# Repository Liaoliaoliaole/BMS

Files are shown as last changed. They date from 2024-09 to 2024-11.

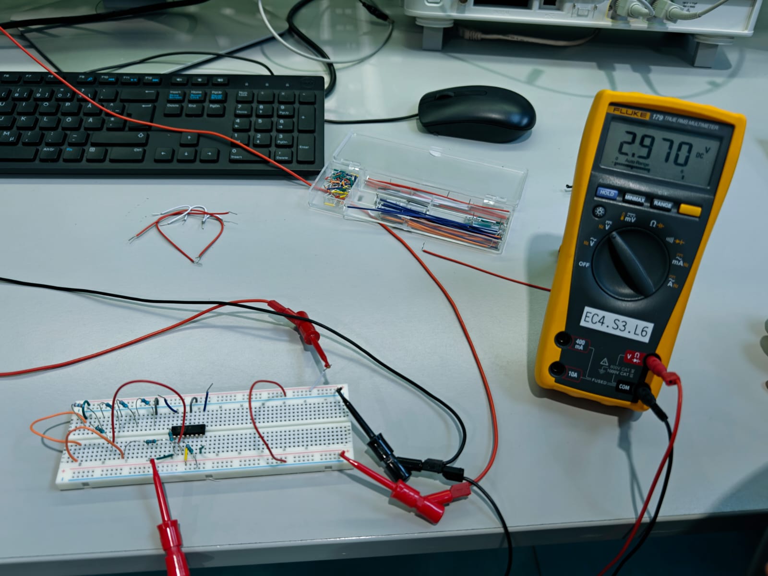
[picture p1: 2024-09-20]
prototyping/Lab1_voltage_measurement/1_LM324N.jpeg

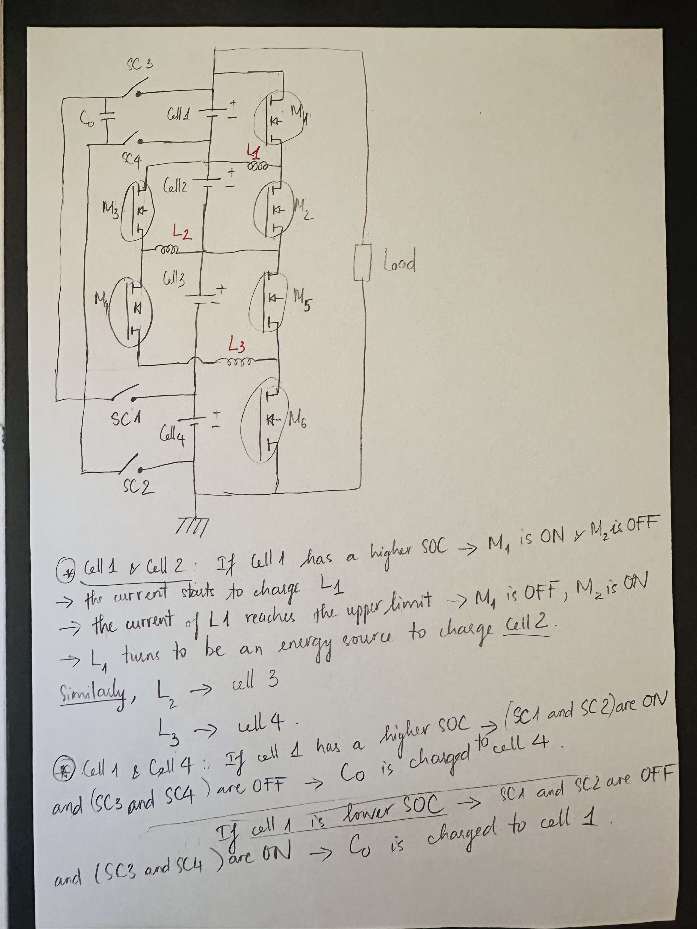
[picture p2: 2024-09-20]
blockdiagram/active_balancing.jpg

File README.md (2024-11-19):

# BMS

# Project Structure

This repository contains the following directories to organize various aspects of the Battery Management System (BMS) project:
Meeting note and scrum report for scrum could be found from [Jira](https://liyuanliull.atlassian.net/jira/software/projects/SCRUM/boards/1/reports).

# `firmware`
The firmware directory includes the BMSServerApp source code. This application runs on the STM32L152RE Nucleo development board.   

## Cross-compilation
### Preconditions:
On Windows:   
- CMake
- Ninja
- STSW-LINK007
- GCC ARM None EABI Compiler

Details of the environment setup can be found in Confluence: [How-To-CrossCompile-BMSServerApp](https://liyuanliull.atlassian.net/wiki/spaces/BMSDEVELOP/pages/426109/How-to+Set+Up+Environment+and+Building+the+BMSServerApp)

### Build scripts
Navigate to the directory where the build script exists.   
Execute the following command in the terminal (such as Windows PowerShell):  
`./build_BMSServerApp.ps1 [-TestBuild]`   

- **Test Build**: Add the optional `-TestBuild` flag to include the testing features in your build, which will enable mock components or extra diagnostics during testing. For example:  
  `./build_BMSServerApp.ps1 -TestBuild`

Then connect the STM32L152RE to your PC, and run:    
`st-flash write BMSServerApp\build\BMSServerApp.bin 0x08000000`   

To remove the build, remove the `build` directory.

## GitHub Actions for CI/CD
The BMSServerApp project also supports automated builds via GitHub Actions. This allows you to build the project in the cloud whenever changes are pushed to the specified branch or a pull request is made.

### Build Types in GitHub Actions:
- The workflow is configured to build three different types: **Debug**, **Release**, and **Test**.
- The **Test** build defines a special `TEST` macro during compilation, enabling mock data and diagnostic features.

### How to Use GitHub Actions:
- **Trigger a Build**: Any push or pull request to the specified branch will automatically trigger the build process.
- **Check Build Status**: Monitor the status of the build in the "Actions" tab of the GitHub repository.
- **Find the Output**:   
  1. Click on the "Actions" tab.
  2. Select the Workflow Run: Find the specific workflow run to view its details.
  3. Scroll down to the "Artifacts" section on the workflow run page. This section shows the files that were uploaded during the workflow execution.
  4. Download the Binary File:  Click on the link for the binary file you want to download (e.g., `BMSServerApp-Debug-bin`, `BMSServerApp-Release-bin`, or `BMSServerApp-Test-bin`).   

# `prototyping`
This directory contains code, configurations, and other resources related to early-stage prototyping of the BMS project. It is used for experimenting with features, creating proof-of-concept implementations, and testing ideas before moving to production.  

- **Breadboard Prototyping**: The breadboard setup for the [current measurement module](https://liyuanliull.atlassian.net/wiki/spaces/BMSDEVELOP/pages/6520833/Voltage+Temperature+and+Current+measurement+Overview) and [temperature measurement prototypes](https://liyuanliull.atlassian.net/wiki/spaces/BMSDEVELOP/pages/8257538/Temperature+Measurement+Module+Prototyping+Documentation.) are stored in confluence.   
- **Calibration Functions**: Software calibration functions are developed to accommodate real-world measurements from the hardware prototypes, especially for [current mesurement](https://liyuanliull.atlassian.net/wiki/spaces/BMSDEVELOP/pages/19791874/Current+measurement+prototyping+and+calibration+calculation).   
Detailed documentation can be found in Confluence.  

# `schematic`
The schematic directory contains electrical and hardware design files, including circuit layouts, component schematics, and PCB designs. These designs are created using KiCad 7.0 and include PCB design files as well. All hardware-related files are stored here for reference.   

# `simulation`
This folder contains simulation models, scripts, and testing environments used for validating the BMS design and performance before physical implementation. Files related to simulation tools, test cases, and results are stored here.   

LTSpice Simulations: Simulation files created in LTSpice are used to validate the electrical design prior to prototyping.   

# `test`
This directory contains both hardware and software test cases and configurations for validating the BMS system.   

**Hardware Testing**: Includes [test cases](https://liyuanliull.atlassian.net/wiki/spaces/BMSDEVELOP/pages/20250626/Hardware+testing+notes) and documentation for validating the physical components of the BMS system: mosfet board, main board, current measurement board and temperature measurement board.   

**Software Testing**: The software testing for the BMSServerApp and BMSClientApp was conducted using several approaches to ensure robust functionality and communication. Key testing scenarios include:     
- ADC Converter Testing: Simulated mock ADC values to validate the proper functioning of the ADC conversion process in the software, ensuring accurate data handling.   
- Modbus Communication Testing: Tested Modbus function code 04 to verify reliable communication between the server and client, ensuring proper data exchange over the Modbus protocol.   
- Grafana Visualization: Validated the integration with Grafana by verifying the display of MCU-sent values on the Grafana dashboard, ensuring accurate and real-time monitoring of system metrics.   
- MOSFET Control Scenarios: Tested various MOSFET control scenarios by simulating different voltage, current, and temperature conditions. This validated the software's ability to control MOSFETs based on these parameters, ensuring correct operation under varying environmental and system conditions.

Detailed results of these hardware and software tests can be found in test dir README.

# `views`
The BMS project uses Grafana for visualization. A short documentation on how to log in and set up Grafana dashboards for monitoring BMS metrics is provided.

### How to Use Grafana

**Logging in as Guest**
1. Access Grafana: Open your web browser and navigate to the [Grafana URL](http://16.16.145.115:3000/login).
2. Guest Login: On the login page use username *Grafana_Viewer* and password *8qr8MzZM*.
3. Browse Dashboards: As a guest, you will have read-only access to the dashboards. You can browse through the available visualizations, interact with the data by zooming in on graphs, and apply filters to view specific data ranges.

**Logging in as Admin**
1. Access Grafana: Open your web browser and navigate to the [Grafana URL](http://16.16.145.115:3000/login).
2. Admin Login: Enter the admin username and password. You can obtain this data on request.
3. Admin Dashboard: Once logged in, you will have full access to all Grafana features, including the ability to create, edit, and delete dashboards, manage data sources, and configure system settings.

**Adding New Visualizations**
1. Add a Panel: Click on "Add new panel" to start creating a new visualization.
2. Select Data Source: Choose the data source from which you want to pull data. This is BMS database in our case.
3. Configure Query: Write the query to fetch the data you need. 
4. Choose Visualization Type: Select the type of visualization you want to create, such as a graph, table or heatmap.
5. Save the Panel: Once you are satisfied with the configuration, click "Apply" to add the panel to your dashboard. Don't forget to save the dashboard itself to retain your changes.

### Testing

**For Test Purposes with Static Values Compile BMSServerApp (STM32) with Symbol TEST**

1. Open the BMSServerApp project in your IDE.
2. Locate the project settings where preprocessor symbols are defined. This is typically found under project properties or build settings.
3. Add the symbol `TEST` to the list of preprocessor definitions.
4. Build the project. This will generate the firmware binary with the test mode enabled.
5. Flash the compiled firmware onto the STM32 microcontroller using a programmer or debugger tool.
6. With the test firmware running, the BMSServerApp will use predefined static values instead of real sensor data, allowing you to test the system's functionality without needing actual sensor inputs.

**For Testing Grafana Without Using STM32 Run `test_data_generator.py` from Views Folder**

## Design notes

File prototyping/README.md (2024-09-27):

1. Lab prototyping for voltage measurement.
2. Lab Prototyping for temperature module documentation:   
https://liyuanliull.atlassian.net/wiki/spaces/BMSDEVELOP/pages/8257538/Temperature+Measurement+Module+Prototyping+Documentation.

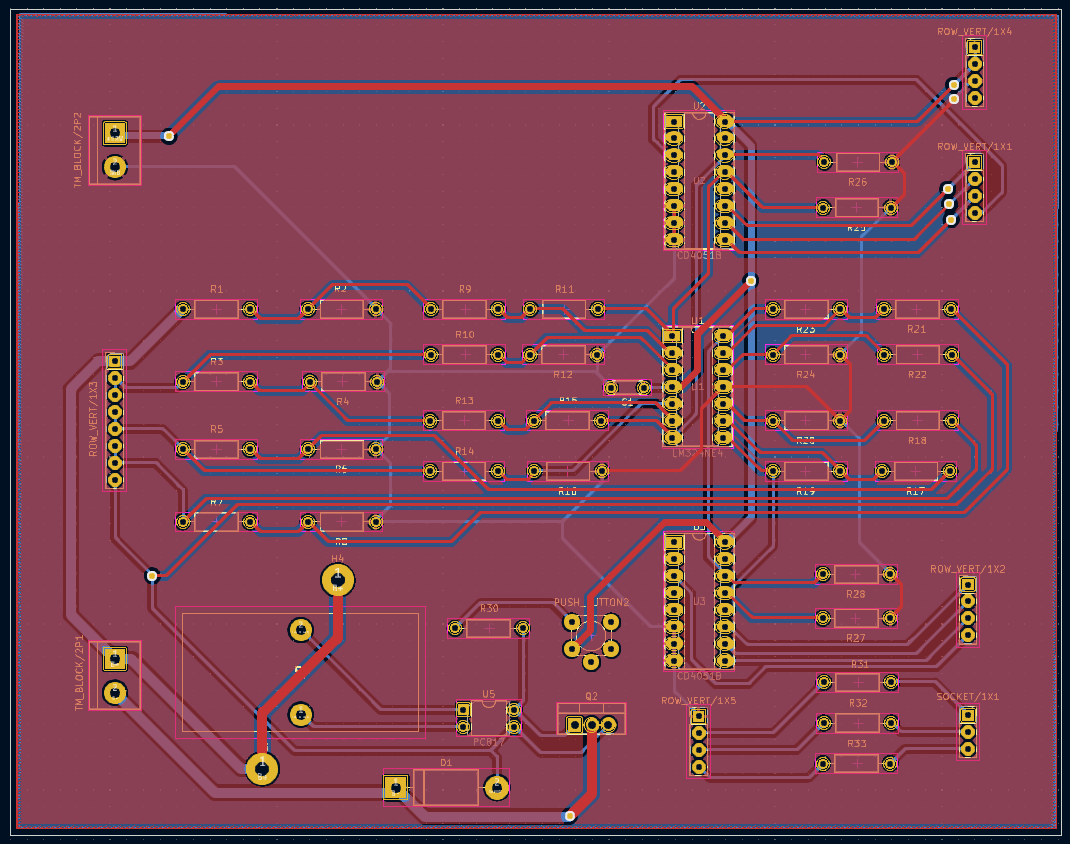
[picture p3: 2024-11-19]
schematic/mainboard_PCBlayout.png

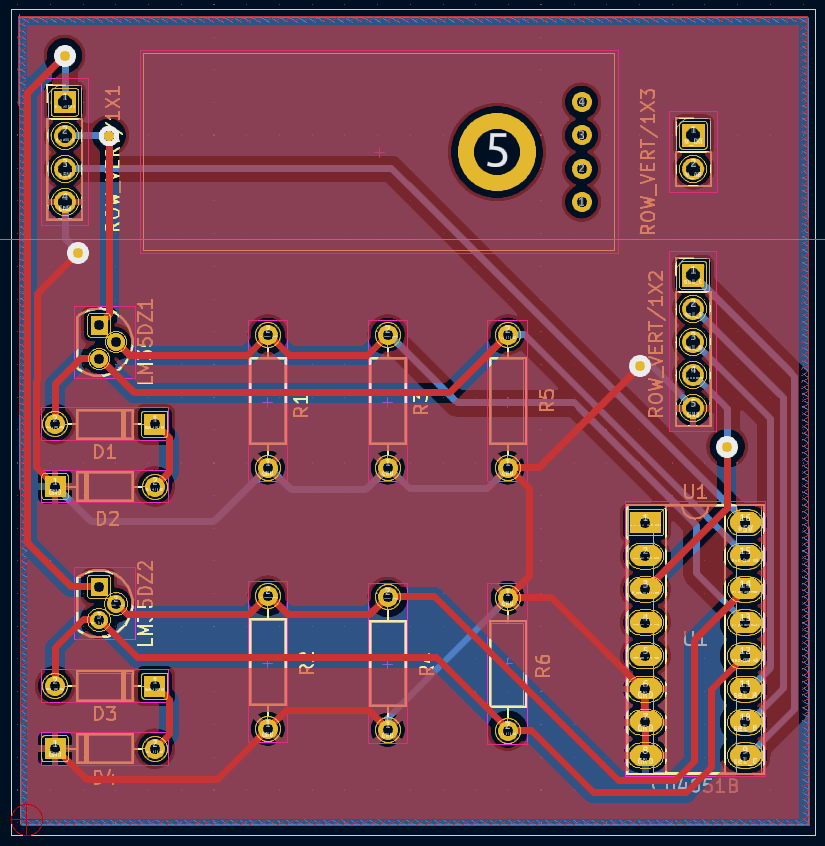
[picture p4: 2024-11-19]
schematic/temperature_PCBlayout.png

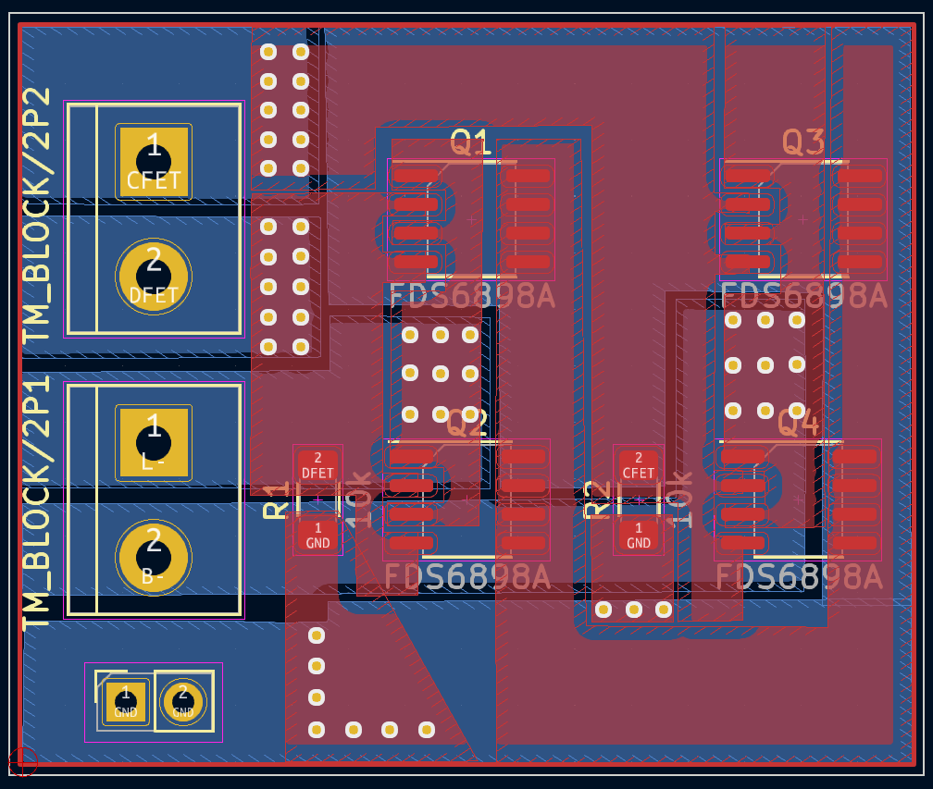
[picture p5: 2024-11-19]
schematic/mosfet_PCBlayout.png

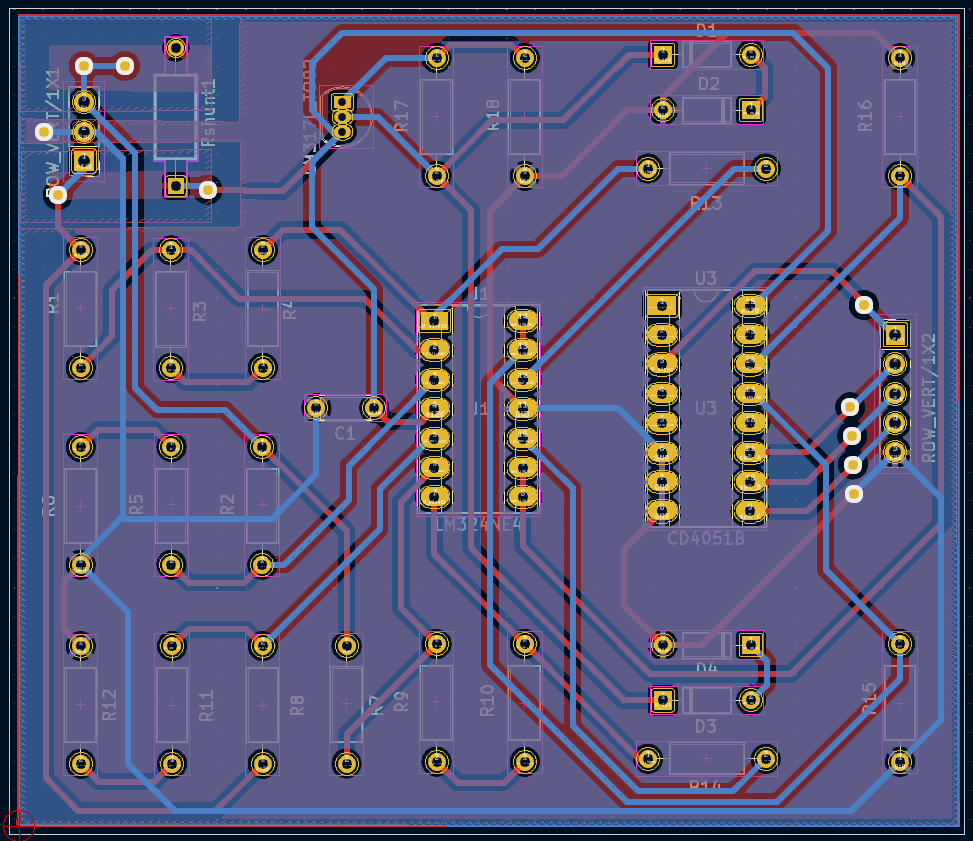
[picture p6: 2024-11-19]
schematic/current_PCBlayout.png

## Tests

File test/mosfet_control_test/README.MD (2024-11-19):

## Test mosfet control logic in PC
Compile:   
`gcc .\test_mosfet.c .\mosfet_control.c -o test`   
Run:   
`./test`   
Should see:   

```
##### Test MOSFET State Control with Sensor Values #####
All faults cleared.
Setting Charge MOSFET: OFF (Internal state: 0)
Setting Discharge MOSFET: OFF
All faults cleared.
All faults cleared.
Setting Charge MOSFET: OFF (Internal state: 0)
Setting Discharge MOSFET: OFF
All faults cleared.
Test Case 1: Temperature -35 degree #####
Debounce Passed: 0
Temperature below -20 C. Setting fault flag.
Debounce Passed: 1
Temperature below -20 C. Setting fault flag.
BOTH_OFF: Charge OFF, Discharge OFF
All faults cleared.
Setting Charge MOSFET: OFF (Internal state: 0)
Setting Discharge MOSFET: OFF
All faults cleared.
Test Case 1: Temperature -15 degree #####
Debounce Passed: 0
Temperature between -20 C and 5 C. Discharge only allowed.
Debounce Passed: 1
Temperature between -20 C and 5 C. Discharge only allowed.
Setting Charge MOSFET: OFF (Internal state: 0)
Setting Discharge MOSFET: ON
DISCHARGE_ONLY: Charge OFF, Discharge ON.
DISCHARGE_ONLY: Charge OFF, Discharge ON
All faults cleared.
Setting Charge MOSFET: OFF (Internal state: 0)
Setting Discharge MOSFET: OFF
All faults cleared.
##### Test Case 1: Temperature 20 degree #####
Debounce Passed: 0
Debounce Passed: 1
Setting Charge MOSFET: ON (Internal state: 1)
Setting Discharge MOSFET: ON
NORMAL_OPERATION: Charge ON, Discharge ON.
NORMAL_OPERATION: Charge ON, Discharge ON
All faults cleared.
Setting Charge MOSFET: OFF (Internal state: 0)
Setting Discharge MOSFET: OFF
All faults cleared.
Test Case 1: Temperature 35 degree #####
Debounce Passed: 0
Temperature between 30 C and 40 C. Discharge only allowed.
Debounce Passed: 1
Temperature between 30 C and 40 C. Discharge only allowed.
Setting Charge MOSFET: OFF (Internal state: 0)
Setting Discharge MOSFET: ON
DISCHARGE_ONLY: Charge OFF, Discharge ON.
DISCHARGE_ONLY: Charge OFF, Discharge ON
All faults cleared.
Setting Charge MOSFET: OFF (Internal state: 0)
Setting Discharge MOSFET: OFF
All faults cleared.
##### Test Case 1: Temperature 45 degree #####
Debounce Passed: 0
Temperature above 40┬░C. Setting fault flag.
Debounce Passed: 1
Temperature above 40┬░C. Setting fault flag.
Setting Charge MOSFET: OFF (Internal state: 0)
Setting Discharge MOSFET: OFF
BOTH_OFF: Charge OFF, Discharge OFF.
BOTH_OFF: Charge OFF, Discharge OFF
##### Test Case 2 :Overcurrent Testing for Normal Temperature Rang #####
All faults cleared.
Setting Charge MOSFET: OFF (Internal state: 0)
Setting Discharge MOSFET: OFF
All faults cleared.
##### Test Case 2: Overcurrent 1.200000 A #####
Debounce Passed: 0
Debounce Passed: 1
Setting Charge MOSFET: ON (Internal state: 1)
Setting Discharge MOSFET: ON
NORMAL_OPERATION: Charge ON, Discharge ON.
NORMAL_OPERATION: Charge ON, Discharge ON
All faults cleared.
Setting Charge MOSFET: OFF (Internal state: 0)
Setting Discharge MOSFET: OFF
All faults cleared.
Test Case 2: Overcurrent 10.000000 A #####
Debounce Passed: 0
High current detected. Body diode protection activated. Turning on both MOSFETs to protect diode.Overcurrent detected. Setting fault flag.
Debounce Passed: 1
Overcurrent detected. Setting fault flag.
OVERCURRENT: Charge OFF, Discharge OFF
All faults cleared.
Setting Charge MOSFET: OFF (Internal state: 0)
Setting Discharge MOSFET: OFF
All faults cleared.
##### Test Case 2: Overcurrent 55.000000 A #####
Debounce Passed: 0
High current detected. Body diode protection activated. Turning on both MOSFETs to protect diode.Overcurrent detected. Setting fault flag.
Debounce Passed: 1
Overcurrent detected. Setting fault flag.
OVERCURRENT: Charge OFF, Discharge OFF
Test Case 3: Voltage Protection #####
All faults cleared.
Setting Charge MOSFET: OFF (Internal state: 0)
Setting Discharge MOSFET: OFF
All faults cleared.
Debounce Passed: 0
Undervoltage detected. Setting fault flag.
Debounce Passed: 1
Undervoltage detected. Setting fault flag.
Setting Charge MOSFET: ON (Internal state: 1)
Setting Discharge MOSFET: OFF
CHARGE_ONLY: Charge ON, Discharge OFF.
#3.1 UNDERVOLTAGE: Charge ON, Discharge OFF
All faults cleared.
Setting Charge MOSFET: OFF (Internal state: 0)
Setting Discharge MOSFET: OFF
All faults cleared.
Debounce Passed: 0
Overvoltage detected. Setting fault flag.
Debounce Passed: 1
Overvoltage detected. Setting fault flag.
Setting Charge MOSFET: OFF (Internal state: 0)
Setting Discharge MOSFET: ON
DISCHARGE_ONLY: Charge OFF, Discharge ON.
#3.2 OVERVOLTAGE: Charge OFF, Discharge ON
All faults cleared.
Setting Charge MOSFET: OFF (Internal state: 0)
Setting Discharge MOSFET: OFF
All faults cleared.
Debounce Passed: 0
Debounce Passed: 1
Setting Charge MOSFET: ON (Internal state: 1)
Setting Discharge MOSFET: ON
NORMAL_OPERATION: Charge ON, Discharge ON.
#3.3 VOLTAGE_NORMAL: Charge ON, Discharge ON
Test Case 4: Body Diode Protection #####
All faults cleared.
Debounce Passed: 0
High current detected. Body diode protection activated. Turning on both MOSFETs to protect diode.Debounce Passed: 1    
#4.1 BODY_DIODE_PROTECTION_TRIGGERED: Charge ON, Discharge ON
Test Case 5: Body Diode Protection Cleared #####
Debounce Passed: 1
Debounce Passed: 1
#4.2 BODY_DIODE_PROTECTION_CLEARED: Charge ON, Discharge ON
All Test Cases Passed
```

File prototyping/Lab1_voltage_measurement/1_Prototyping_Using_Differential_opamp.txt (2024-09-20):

Prototyping Using a Differential Amplifier for Voltage Measurement

1. Choosing Which Input Connects to the Higher Voltage
The differential amplifier has two inputs:

Non-inverting input (+): This input adds the incoming voltage.
Inverting input (-): This input subtracts the incoming voltage.
To decide which input should connect to the higher voltage, it's important to consider the expected polarity of the output signal. The differential amplifier amplifies the difference between the two inputs as: 
𝑉out=𝐴×(𝑉+ − 𝑉−)Where:
V +  is the voltage at the non-inverting terminal (+)
𝑉−  is the voltage at the inverting terminal (-)
A is the gain of the amplifier.（R3/R1）
For positive output voltage:
Connect the higher voltage to the non-inverting input (+) and the lower voltage to the inverting input (-). This ensures a positive output voltage, as 𝑉+>𝑉−.
For negative output voltage:

Connect the higher voltage to the inverting input (-) and the lower voltage to the non-inverting input (+). This results in a negative output voltage.
Our opamp connected GND not negative power souce, so cant go negative value, where expect a positive difference (e.g., measuring the voltage drop across a component), connect the higher voltage to the non-inverting input.

2.  Breadboard Resistance and Resistor Tolerance Affecting Measurement
When building circuits on a breadboard, several factors can introduce measurement errors, particularly small resistances and tolerances:Breadboard Resistance:This resistance can introduce voltage drops, especially if working with high-precision measurements or low-resistance components.

Resistor Tolerance:Resistors come with a tolerance value (e.g., ±1%, ±5%), indicating how much the actual resistance can deviate from the nominal value.
Effect on Measurement: In voltage dividers, even small deviations can result in incorrect voltage drops, affecting VALUE readings.

3. Calibration.
Baseline Measurement:measure known reference voltages at different points in the circuit. For instance, use a calibrated multimeter to measure the actual voltages.
Create a Calibration Curve:Record the corresponding output from differential amplifier.

Create a Calibration Curve: 
Based on the recorded data, establish a relationship between the actual voltage and the measured values.could be linear (if the amplifier behaves ideally) or slightly non-linear depending on . For example, linear:
Use software to map the measured ADC values to actual voltages. A simple linear calibration can be applied using:
𝑉actual=𝑚×𝑉measured+𝑏
Where 𝑚 is the slope and 𝑏 is the intercept, both determined from calibration data.

example
m = 0.99  # Slope from calibration curve
b = 0.02  # Offset from calibration curve

def calibrated_voltage(raw_adc_value):
    measured_voltage = raw_adc_value * (V_ref / ADC_max_value)  
    actual_voltage = m * measured_voltage + b
    return actual_voltage

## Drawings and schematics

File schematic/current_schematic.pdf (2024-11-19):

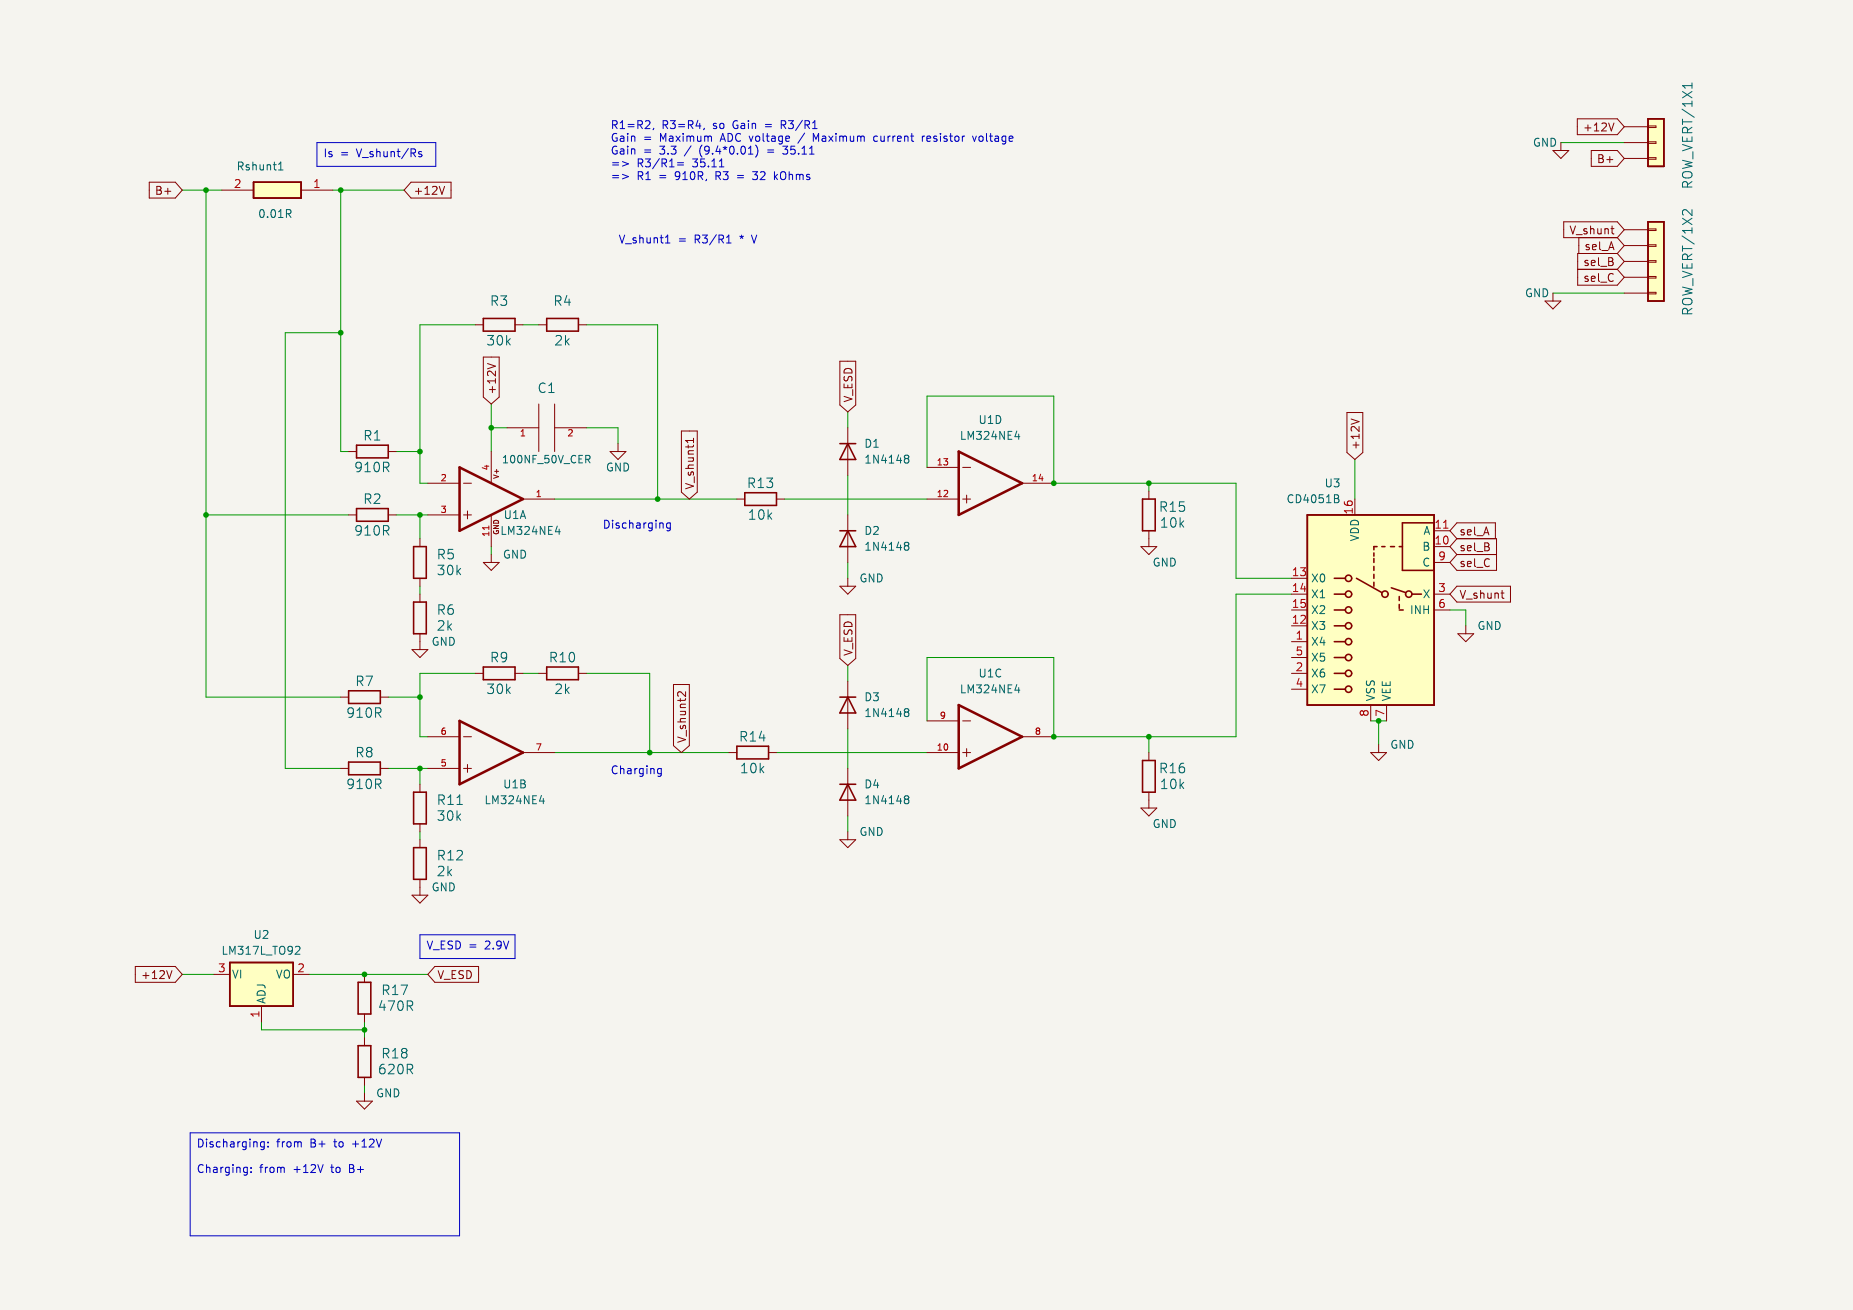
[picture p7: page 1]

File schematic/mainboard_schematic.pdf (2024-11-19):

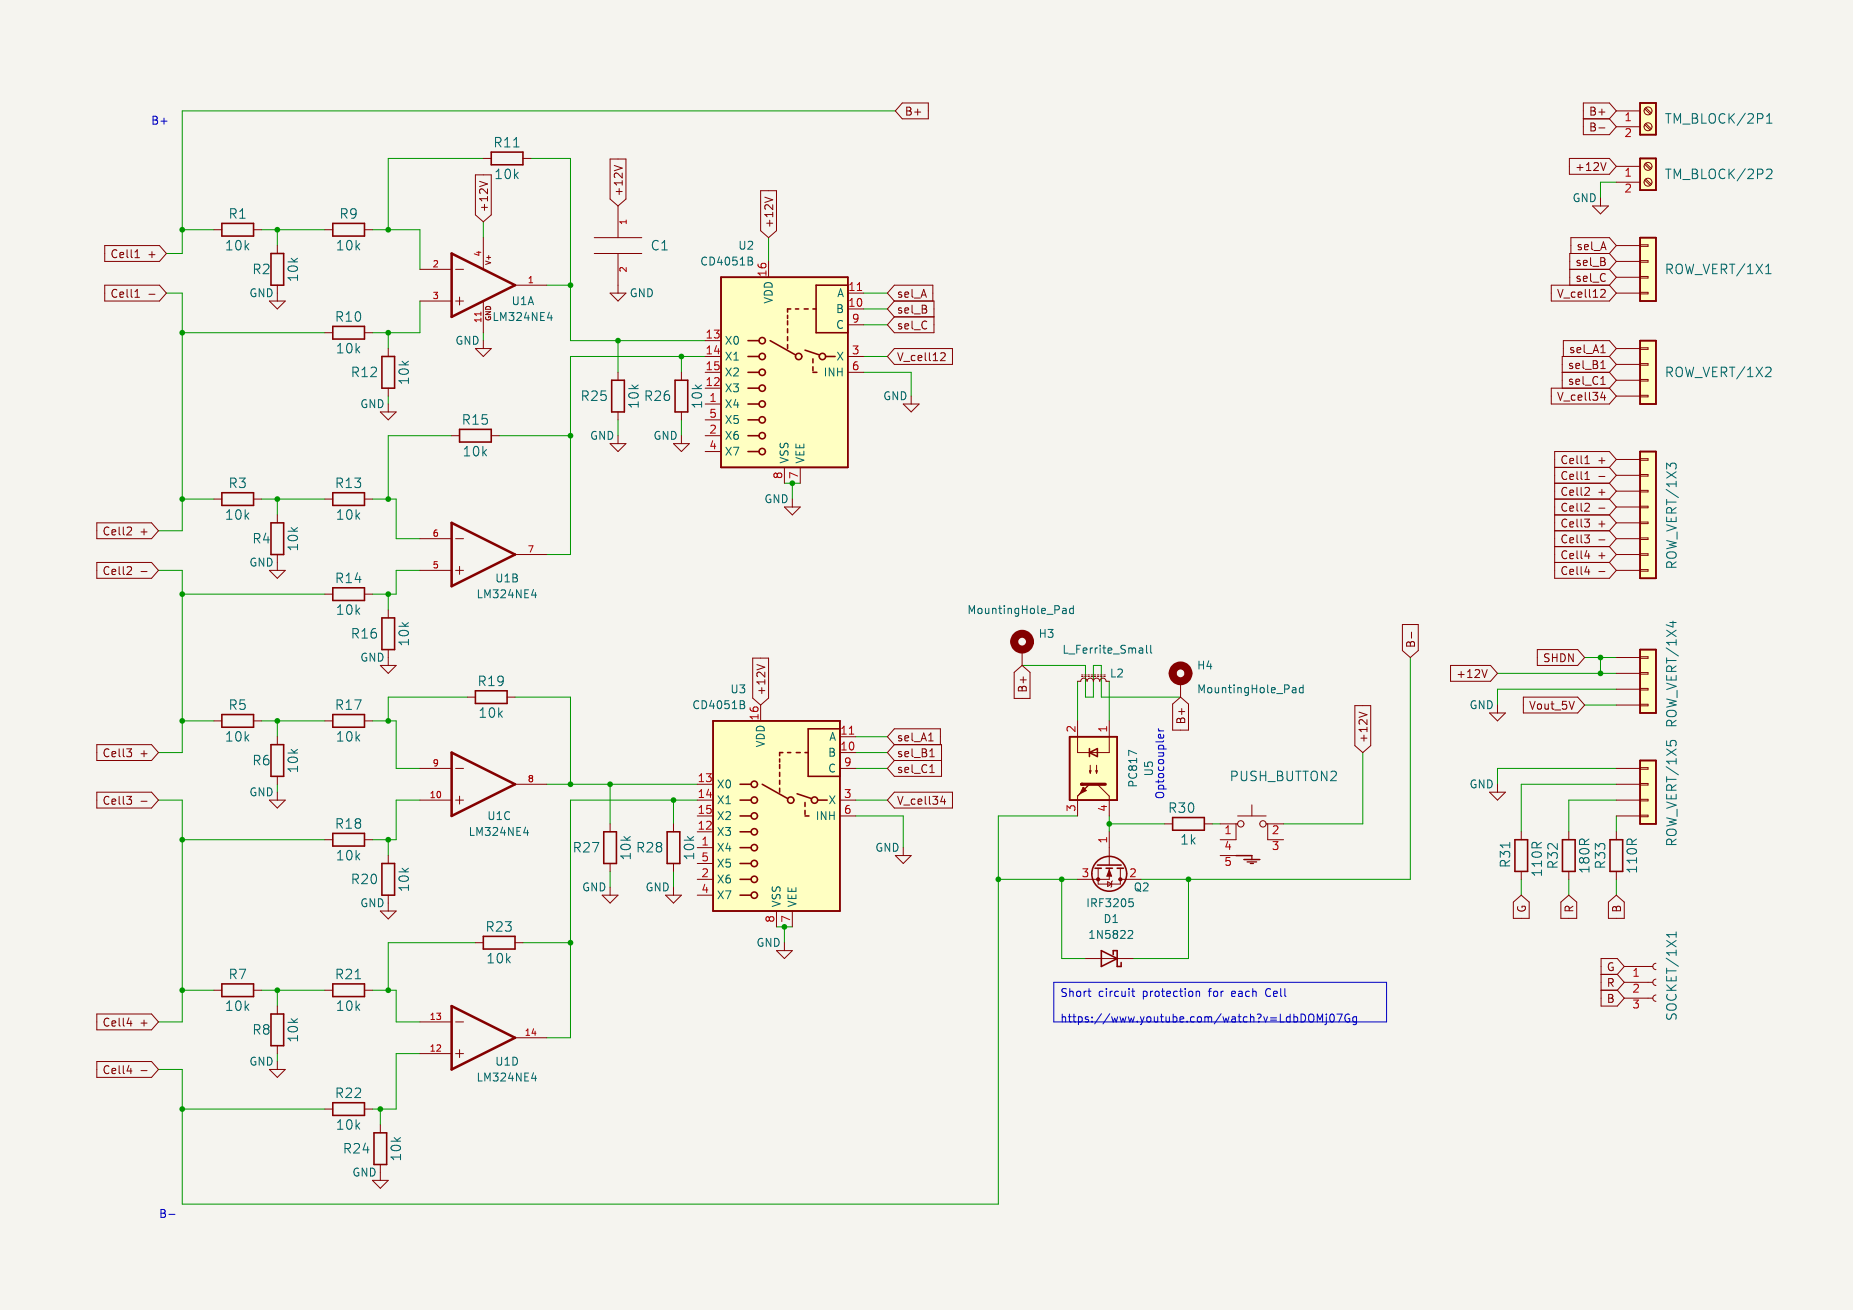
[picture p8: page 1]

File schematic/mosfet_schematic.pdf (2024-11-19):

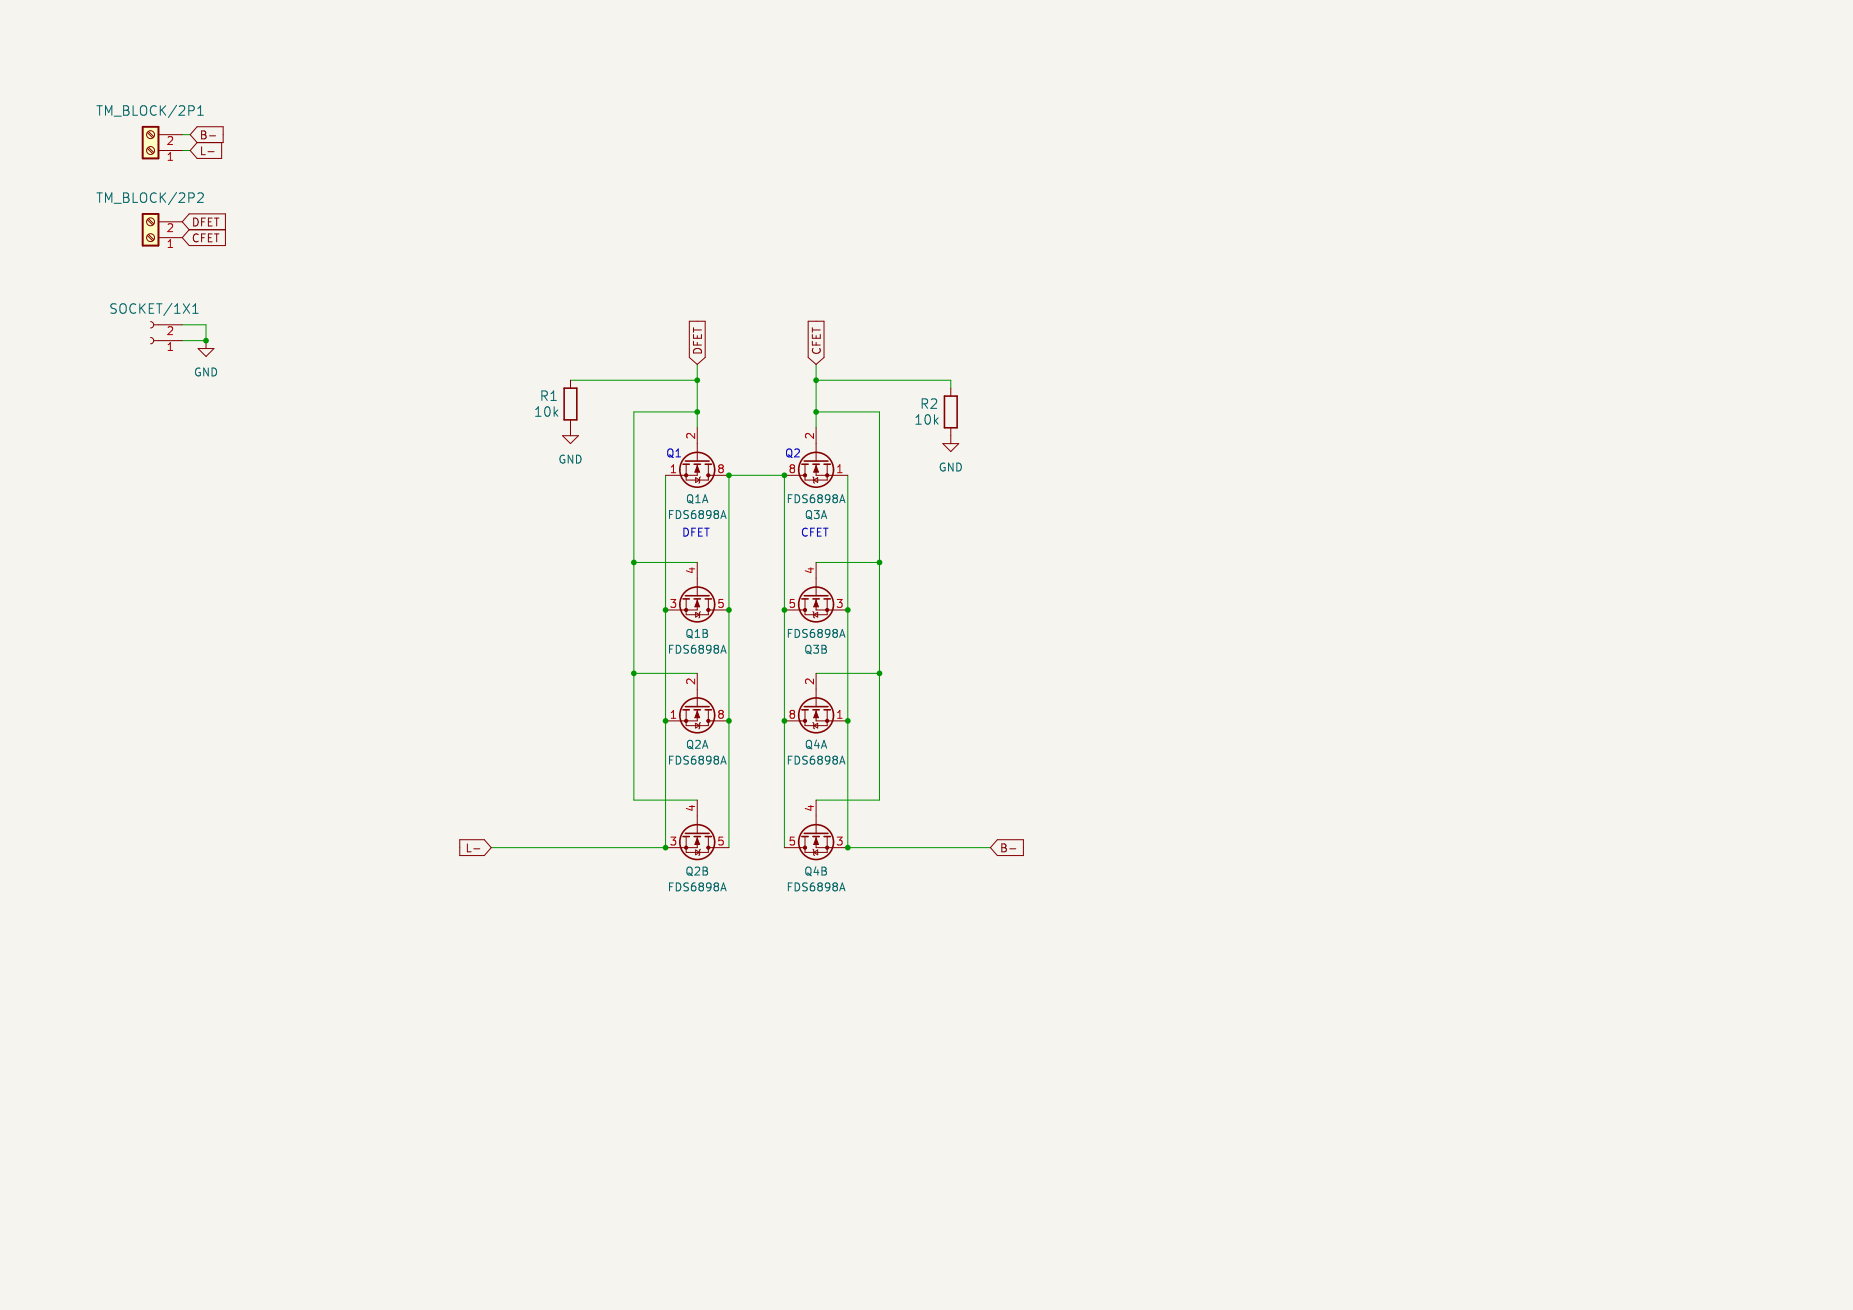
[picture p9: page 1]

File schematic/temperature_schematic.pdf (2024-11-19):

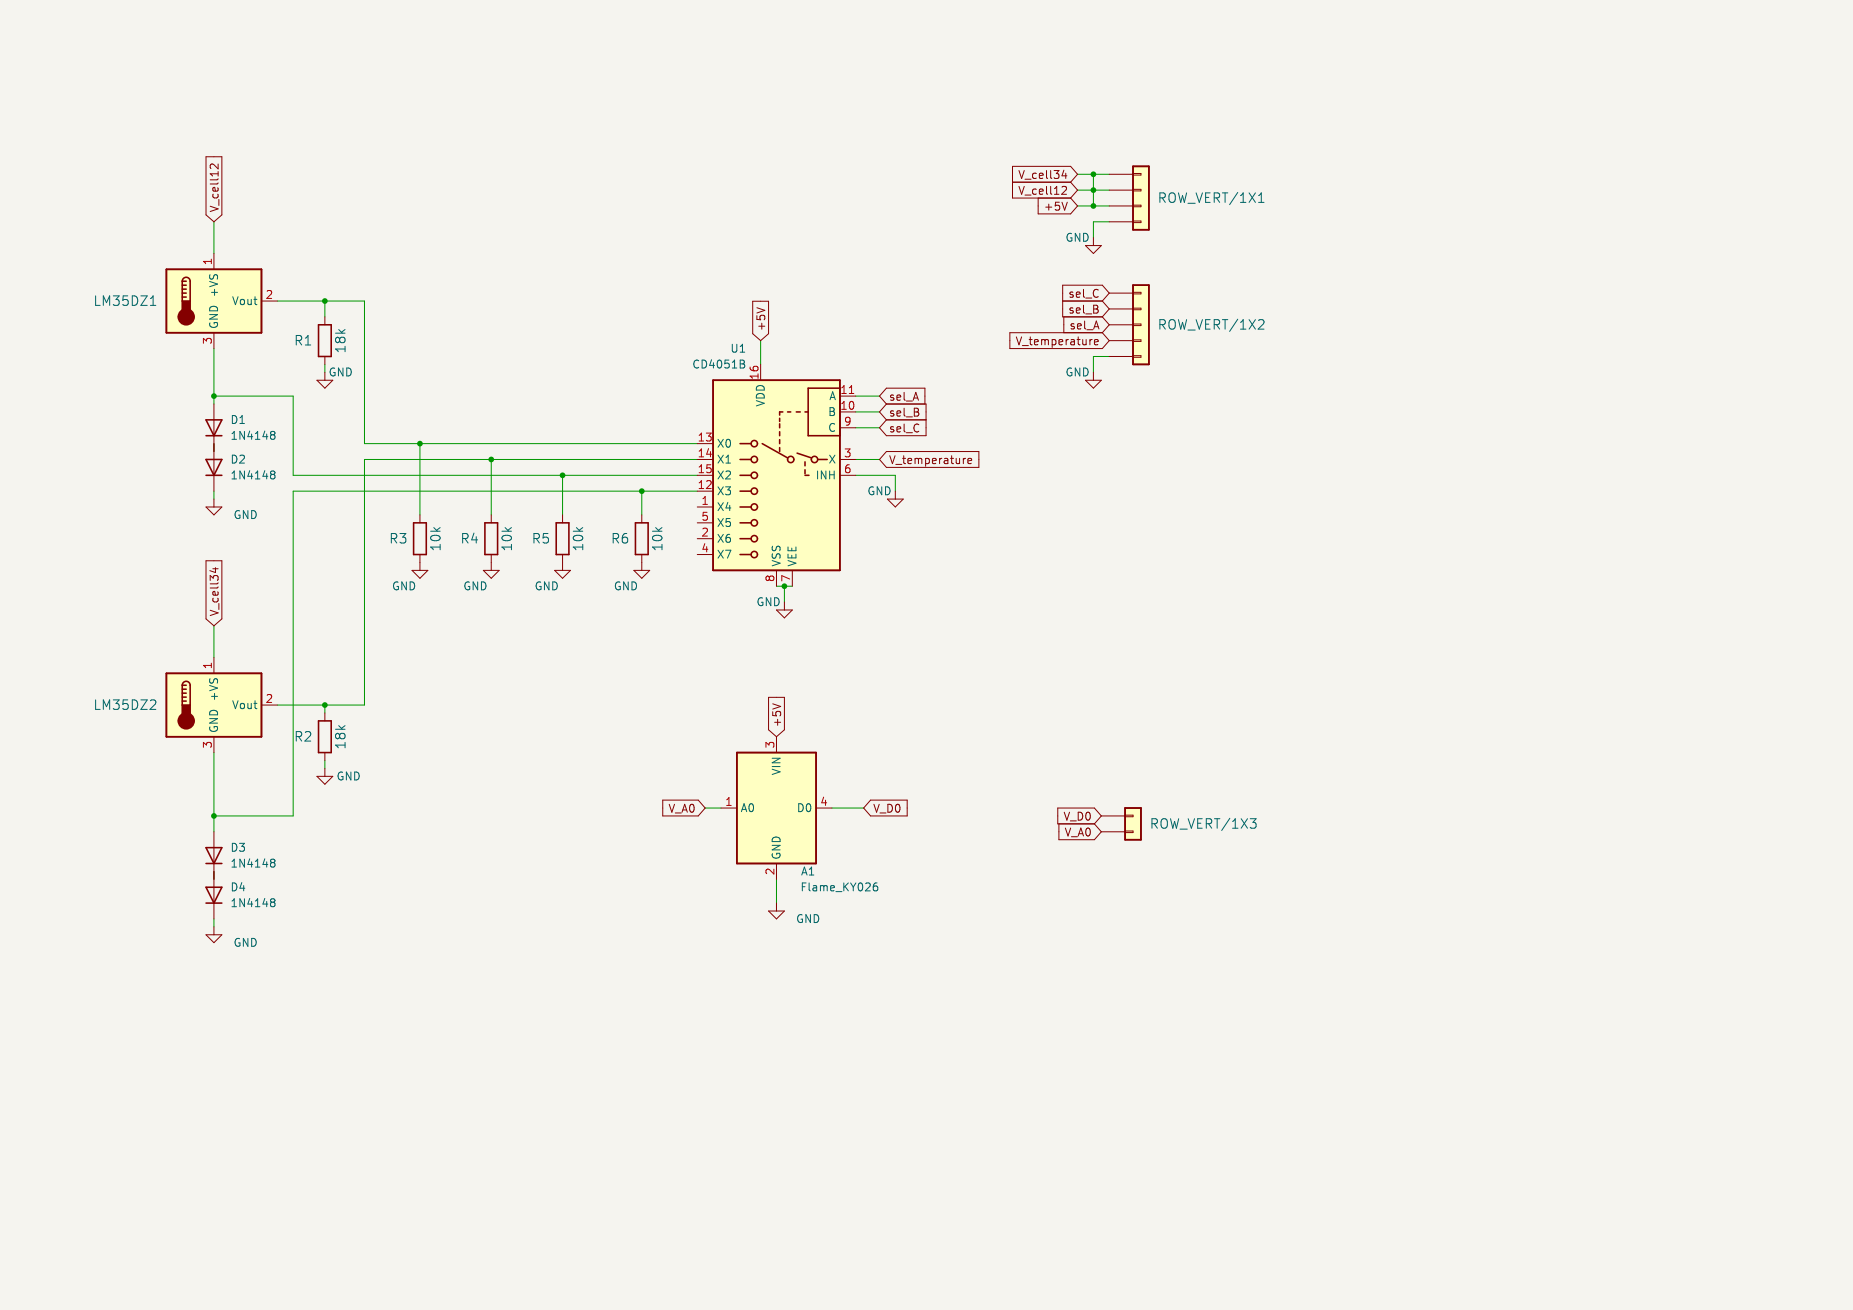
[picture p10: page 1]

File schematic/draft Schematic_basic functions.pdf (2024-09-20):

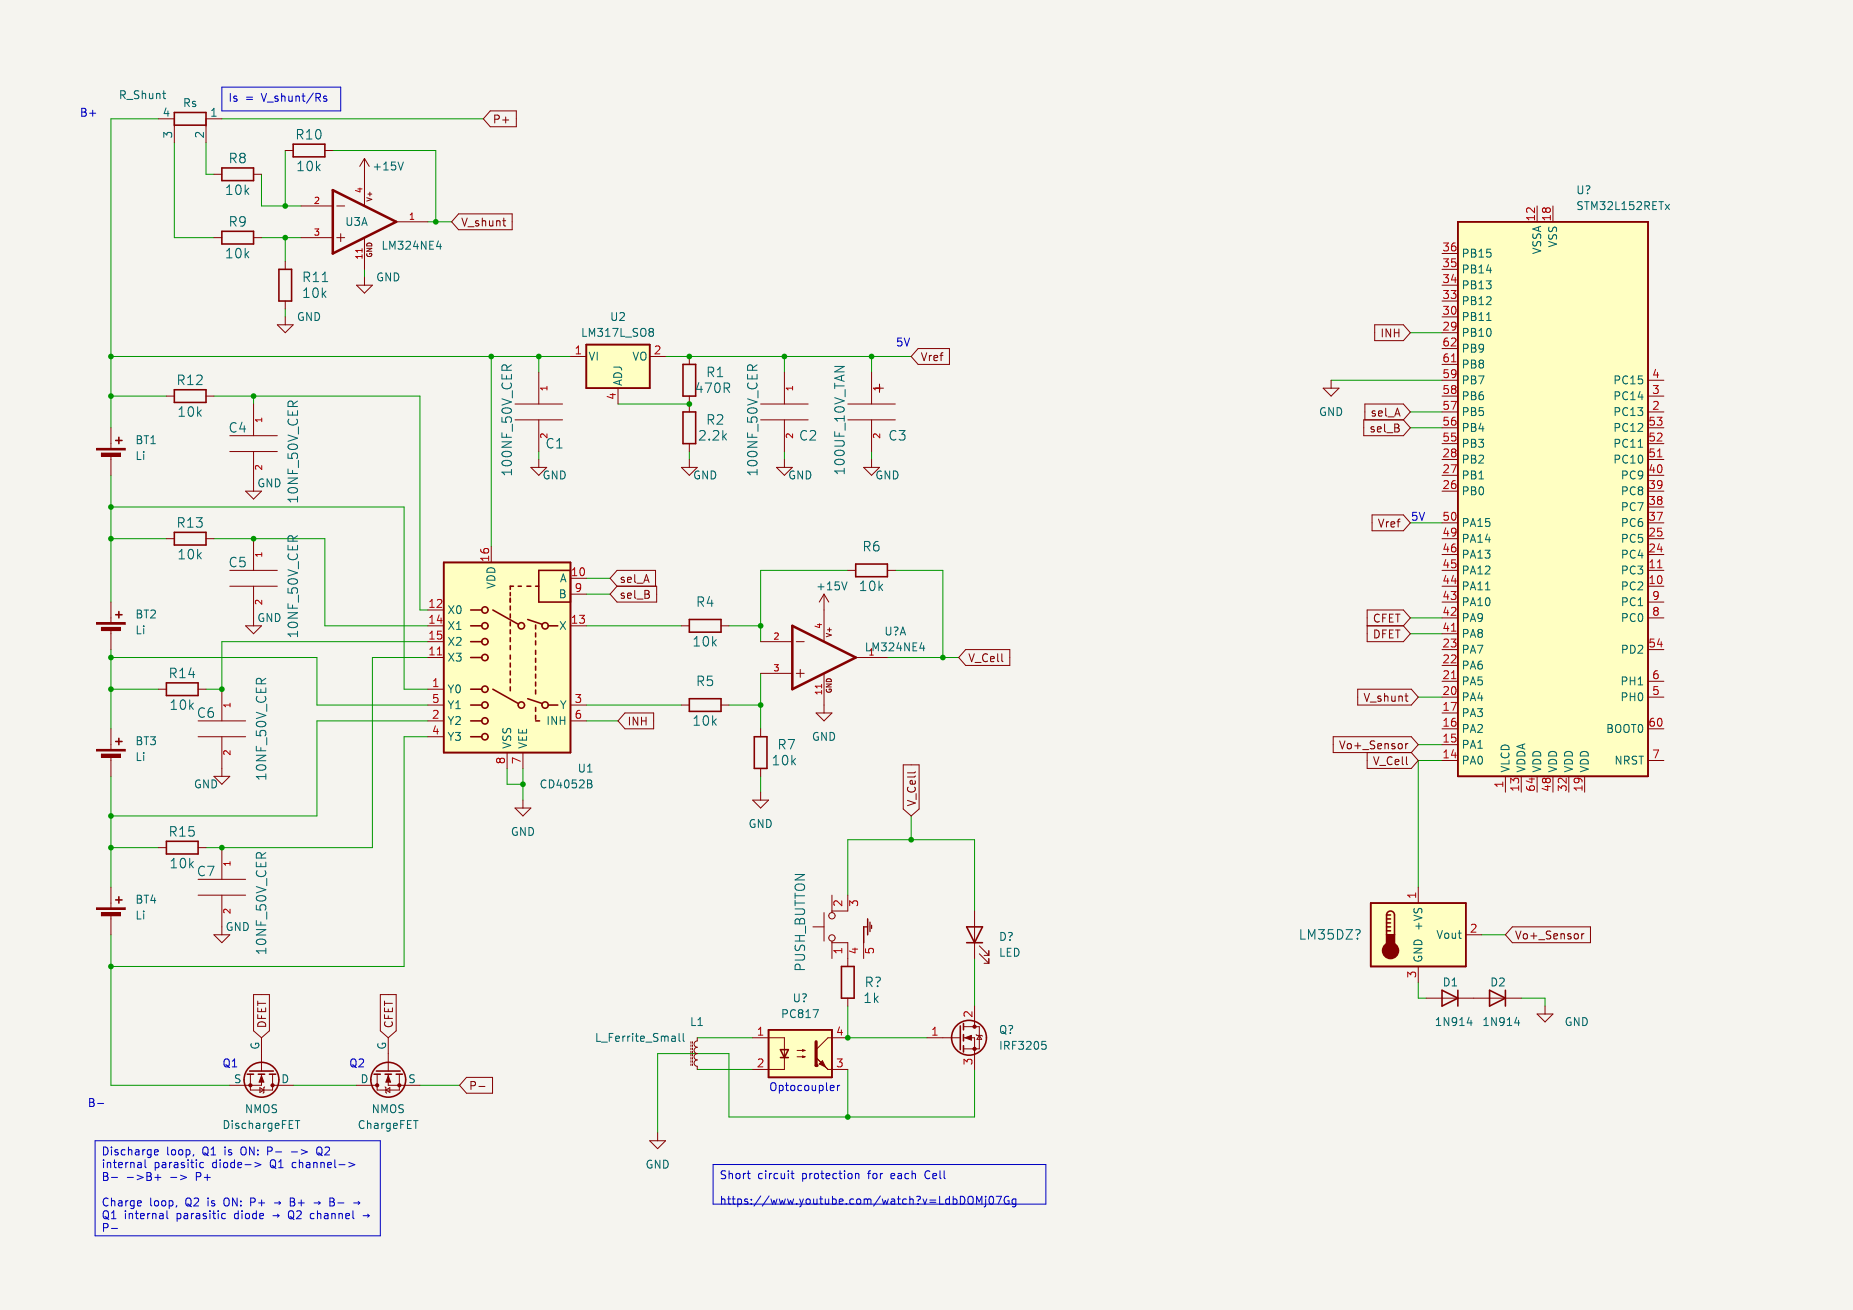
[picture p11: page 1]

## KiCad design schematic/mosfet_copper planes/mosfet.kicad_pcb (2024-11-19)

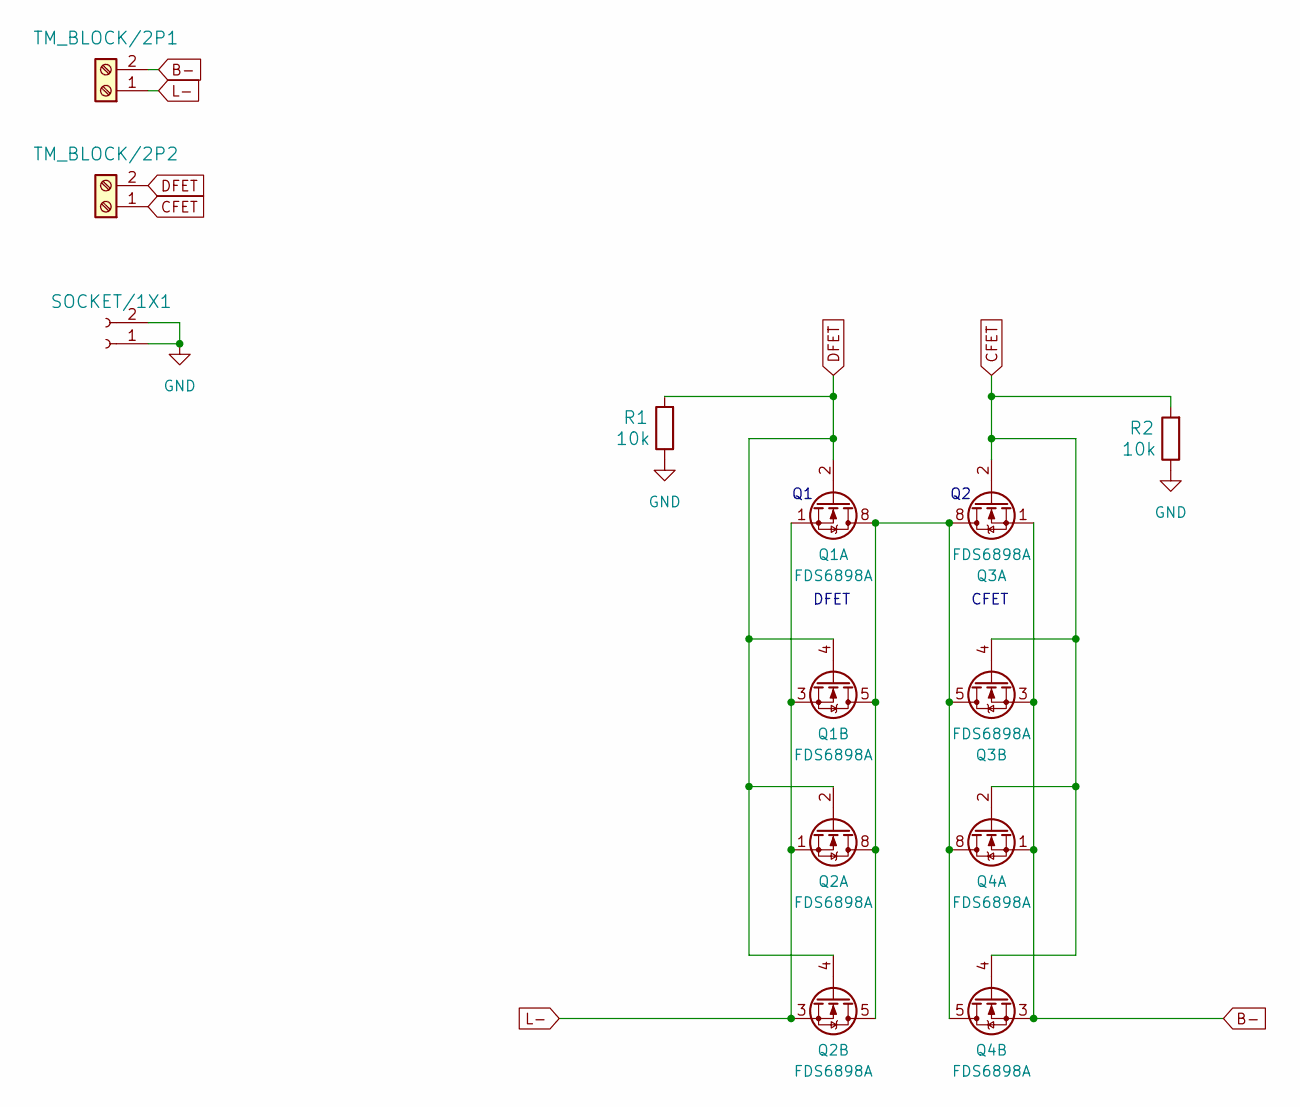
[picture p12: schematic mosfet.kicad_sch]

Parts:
Q1, Q2, Q3, Q4: FDS6898A; SOIC-8_3.9x4.9mm_P1.27mm
R1, R2: 10k; 1206; Tolerance +-5%
SOCKET/1X1: SOCKET_1X2; SOCKET_1x2
TM_BLOCK/2P1, TM_BLOCK/2P2: TM_BLOCK_2P

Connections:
B-: Q3.1 (S1), Q3.3 (S2), Q4.1 (S1), Q4.3 (S2), TM_BLOCK/2P1.2
CFET: Q3.2 (G1), Q3.4 (G2), Q4.2 (G1), Q4.4 (G2), R2.2, TM_BLOCK/2P2.1
DFET: Q1.2 (G1), Q1.4 (G2), Q2.2 (G1), Q2.4 (G2), R1.2, TM_BLOCK/2P2.2
GND: R1.1, R2.1, SOCKET/1X1.1, SOCKET/1X1.2
L-: Q1.1 (S1), Q1.3 (S2), Q2.1 (S1), Q2.3 (S2), TM_BLOCK/2P1.1
unnamed: Q1.5 (D2), Q1.6 (D2), Q1.7 (D1), Q1.8 (D1), Q2.5 (D2), Q2.6 (D2), Q2.7 (D1), Q2.8 (D1), Q3.5 (D2), Q3.6 (D2), Q3.7 (D1), Q3.8 (D1), Q4.5 (D2), Q4.6 (D2), Q4.7 (D1), Q4.8 (D1)

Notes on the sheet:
DFET
CFET

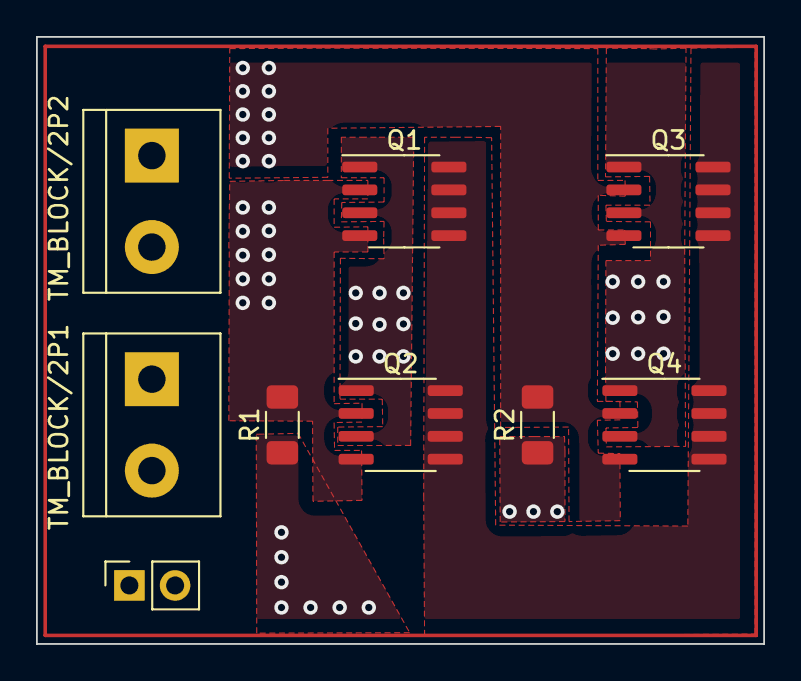
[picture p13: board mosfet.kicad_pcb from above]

Board: 2 copper layers, 40.4 x 33.7 mm, 9 parts (0 on the bottom side), 6 nets.

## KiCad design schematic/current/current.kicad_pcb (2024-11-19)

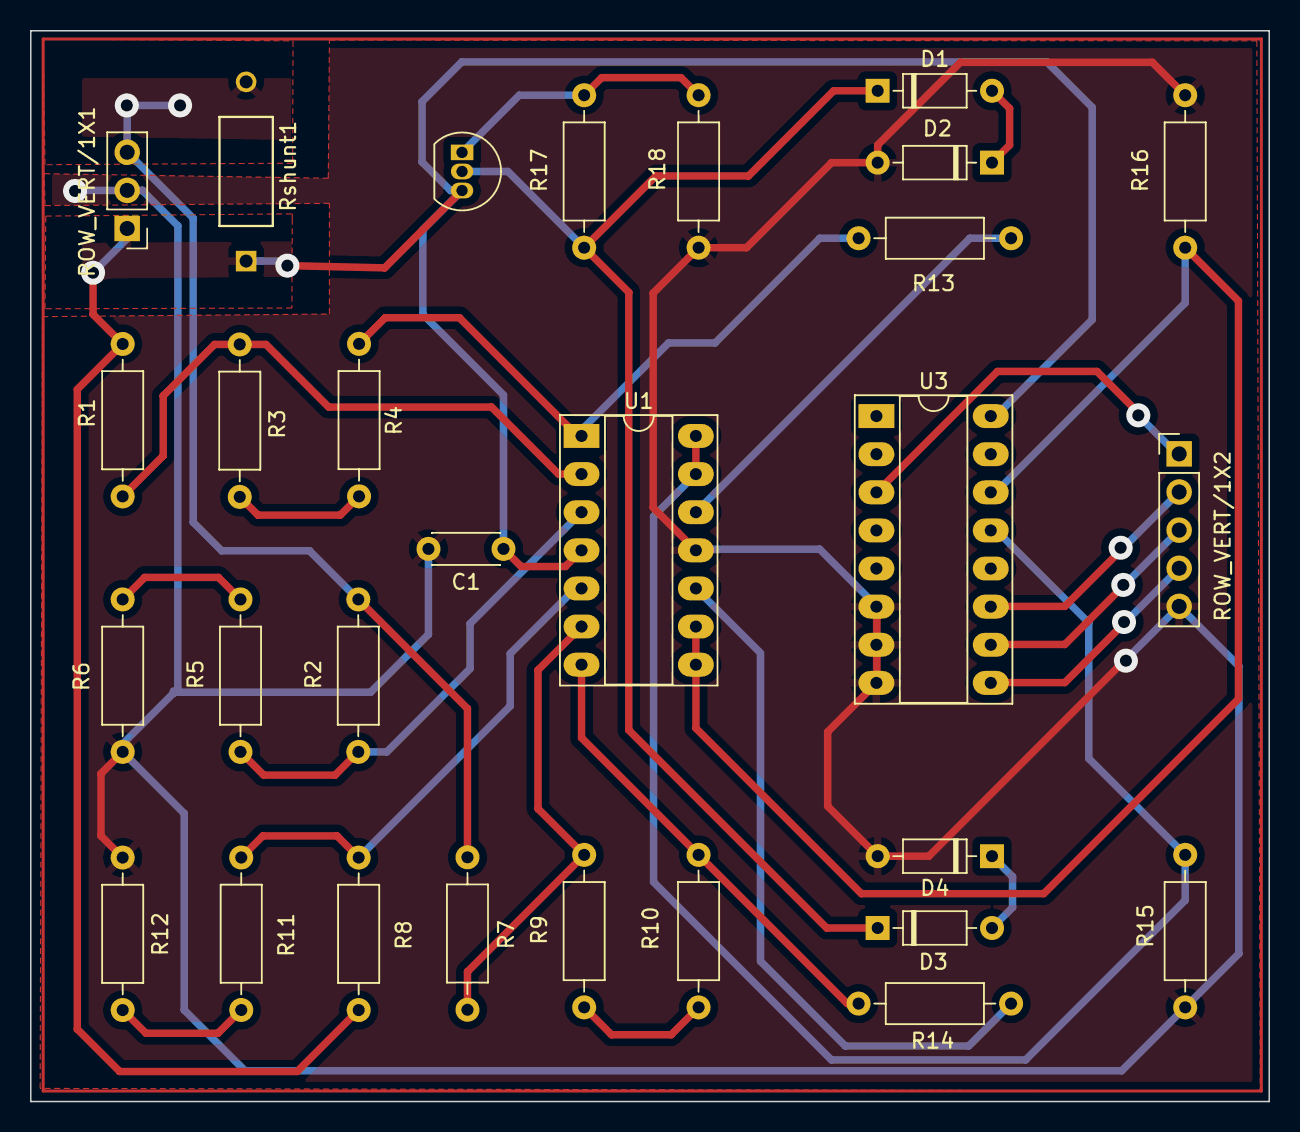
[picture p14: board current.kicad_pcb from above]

Board: 2 copper layers, 82.5 x 71.4 mm, 29 parts (0 on the bottom side), 25 nets.

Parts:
C1: 100NF_50V_CER; C5_0
D1, D2, D3, D4: 1N4148; D_DO-35_SOD27_P7.62mm_Horizontal
R1, R2, R7, R8: 910R; R3_5W
R3, R5, R9, R11: 30k; R3_5W
R4, R6, R10, R12: 2k; R3_5W
R13, R14, R15, R16: 10k; R3_5W
R17: 470R; R3_5W
R18: 620R; R3_5W
ROW_VERT/1X1: ROW_VERT_1X3; ROW_VERT_1x3
ROW_VERT/1X2: ROW_VERT_1X5; ROW_VERT_1x5
Rshunt1: 0.01R; RES_WH&slash_NB_OHM
U1: LM324NE4; DIP-14_W7.62mm_Socket_LongPads
U2: LM317L_TO92; TO-92_Inline
U3: CD4051B; DIP-16_W7.62mm_Socket_LongPads

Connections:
+12V: C1.1, R1.1, R8.1, ROW_VERT/1X1.1, Rshunt1.1, U1.4, U2.3 (VI), U3.16 (VDD)
B+: R2.1, R7.1, ROW_VERT/1X1.3, Rshunt1.2
GND: C1.2, D2.2 (A), D4.2 (A), R6.1, R12.1, R15.1, R16.1, R18.1, ROW_VERT/1X1.2, ROW_VERT/1X2.5, U1.11, U3.6 (INH), U3.7 (VEE), U3.8 (VSS)
unnamed: D1.2 (A), D2.1 (K)
unnamed: D3.2 (A), D4.1 (K)
unnamed: R1.2, R3.1, U1.2
unnamed: R2.2, R5.2, U1.3
unnamed: R3.2, R4.1
unnamed: R5.1, R6.2
unnamed: R7.2, R9.1, U1.6
unnamed: R9.2, R10.1
unnamed: R11.1, R12.2
unnamed: R8.2, R11.2, U1.5
unnamed: R13.2, U1.12
unnamed: R14.2, U1.10
unnamed: R17.1, R18.2, U2.1 (ADJ)
unnamed: R15.2, U1.13, U1.14, U3.13 (X0)
unnamed: R16.2, U1.8, U1.9, U3.14 (X1)
V_ESD: D1.1 (K), D3.1 (K), R17.2, U2.2 (VO)
V_shunt: ROW_VERT/1X2.1, U3.3 (X)
V_shunt1: R4.2, R13.1, U1.1
V_shunt2: R10.2, R14.1, U1.7
sel_A: ROW_VERT/1X2.2, U3.11 (A)
sel_B: ROW_VERT/1X2.3, U3.10 (B)
sel_C: ROW_VERT/1X2.4, U3.9 (C)

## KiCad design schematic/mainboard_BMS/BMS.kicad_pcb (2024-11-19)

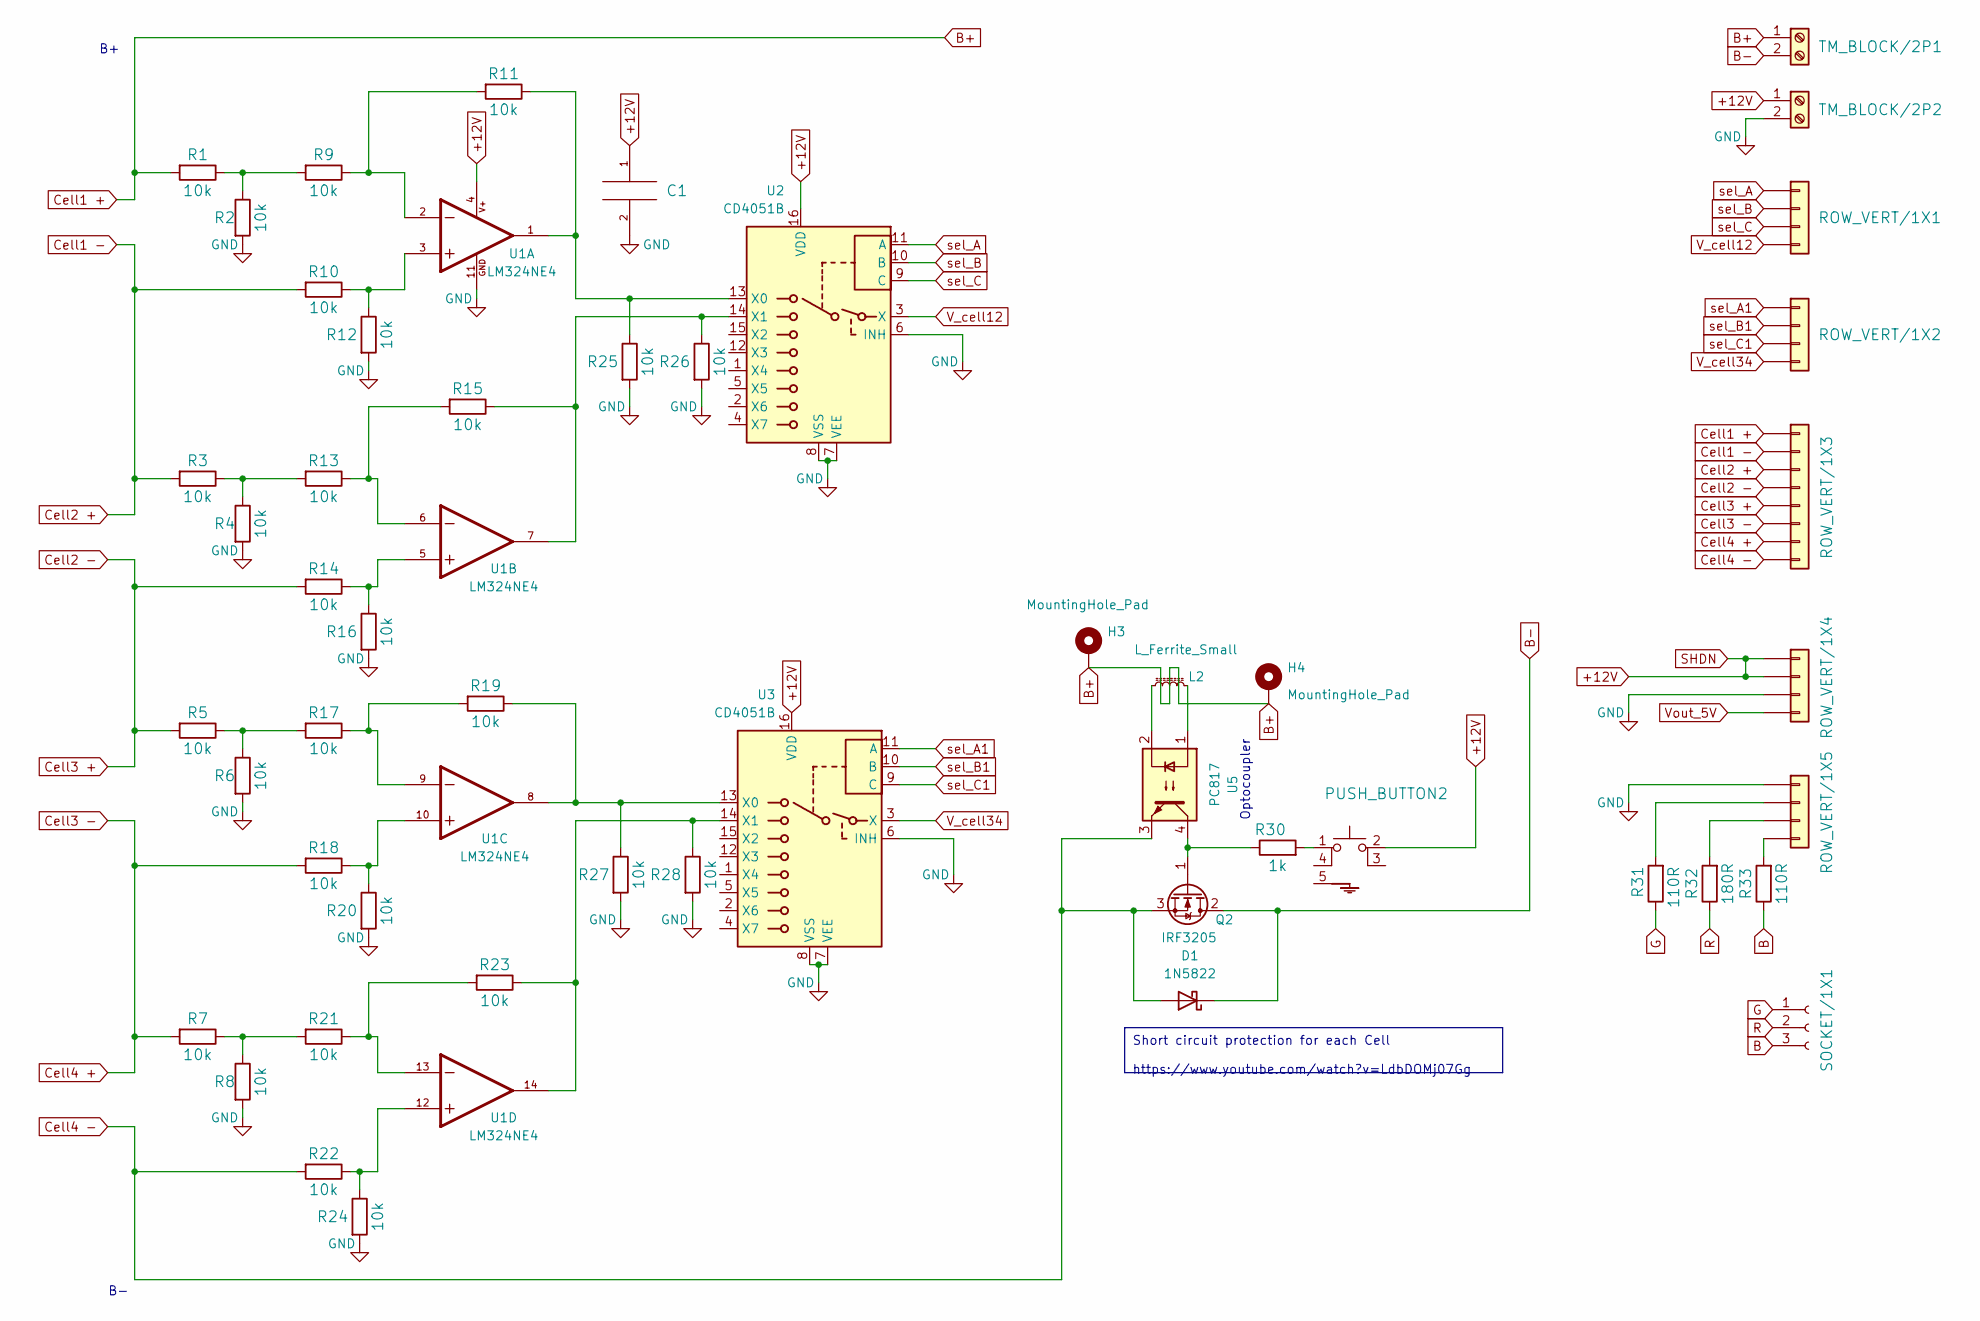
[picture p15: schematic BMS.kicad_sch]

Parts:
C1: 100NF_50V_CER; C5_0; Tolerance +-10%
D1: 1N5822; D_DO-201AD_P15.24mm_Horizontal
H3, H4: MountingHole_Pad; MountingHole_2.2mm_M2_Pad
L2: L_Ferrite_Small; PE92112KNL
PUSH_BUTTON2: PUSH_BUTTON; SKHHQV
Q2: IRF3205; TO-220-3_Vertical
R1, R2, R3, R4, R5, R6, R7, R8, R9, R10, R11, R12, R13, R14, R15, R16, R17, R18, R19, R20, R21, R22, R23, R24, R25, R26, R27, R28: 10k; R3_5W; Tolerance +-1%
R30: 1k; R3_5W; Tolerance +-1%
R31, R33: 110R; R3_5W; Tolerance +-1%
R32: 180R; R3_5W; Tolerance +-1%
ROW_VERT/1X1, ROW_VERT/1X2, ROW_VERT/1X4, ROW_VERT/1X5: ROW_VERT_1X4; ROW_VERT_1x4
ROW_VERT/1X3: ROW_VERT_1X8; ROW_VERT_1x8
SOCKET/1X1: SOCKET_1X3; SOCKET_1x3
TM_BLOCK/2P1, TM_BLOCK/2P2: TM_BLOCK_2P
U1: LM324NE4; DIP-14_W7.62mm_Socket_LongPads; PARTREV D
U2, U3: CD4051B; DIP-16_W7.62mm_Socket_LongPads
U5: PC817; DIP-4_W7.62mm

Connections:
+12V: C1.1, PUSH_BUTTON2.2 (A), ROW_VERT/1X4.1, ROW_VERT/1X4.2, TM_BLOCK/2P2.1, U1.4, U2.16 (VDD), U3.16 (VDD)
B: R33.1, SOCKET/1X1.3
B+: H3.1, H4.1, R1.2, ROW_VERT/1X3.1, TM_BLOCK/2P1.1
B-: D1.1 (K), Q2.2 (D), TM_BLOCK/2P1.2
Cell1 -: R3.2, R10.2, ROW_VERT/1X3.2, ROW_VERT/1X3.3
Cell2 -: R5.2, R14.2, ROW_VERT/1X3.4, ROW_VERT/1X3.5
Cell3 -: R7.2, R18.2, ROW_VERT/1X3.6, ROW_VERT/1X3.7
Cell4 -: D1.2 (A), Q2.3 (S), R22.2, ROW_VERT/1X3.8, U5.3
G: R31.1, SOCKET/1X1.1
GND: C1.2, R2.2, R4.2, R6.2, R8.2, R12.2, R16.2, R20.2, R24.2, R25.2, R26.2, R27.2, R28.2, ROW_VERT/1X4.3, ROW_VERT/1X5.1, TM_BLOCK/2P2.2, U1.11, U2.6 (INH), U2.7 (VEE), U2.8 (VSS), U3.6 (INH), U3.7 (VEE), U3.8 (VSS)
unnamed: L2.1, U5.2
unnamed: L2.2, U5.1
unnamed: PUSH_BUTTON2.1, R30.2
unnamed: Q2.1 (G), R30.1, U5.4
unnamed: R1.1, R2.1, R9.2
unnamed: R10.1, R12.1, U1.3
unnamed: R9.1, R11.2, U1.2
unnamed: R13.1, R15.2, U1.6
unnamed: R3.1, R4.1, R13.2
unnamed: R14.1, R16.1, U1.5
unnamed: R17.1, R19.2, U1.9
unnamed: R5.1, R6.1, R17.2
unnamed: R18.1, R20.1, U1.10
unnamed: R21.1, R23.2, U1.13
unnamed: R7.1, R8.1, R21.2
unnamed: R22.1, R24.1, U1.12
unnamed: R31.2, ROW_VERT/1X5.2
unnamed: R32.2, ROW_VERT/1X5.3
unnamed: R33.2, ROW_VERT/1X5.4
unnamed: R11.1, R25.1, U1.1, U2.13 (X0)
unnamed: R15.1, R26.1, U1.7, U2.14 (X1)
unnamed: R19.1, R27.1, U1.8, U3.13 (X0)
unnamed: R23.1, R28.1, U1.14, U3.14 (X1)
R: R32.1, SOCKET/1X1.2
V_cell12: ROW_VERT/1X1.4, U2.3 (X)
V_cell34: ROW_VERT/1X2.4, U3.3 (X)
Vout_5V: ROW_VERT/1X4.4
sel_A: ROW_VERT/1X1.1, U2.11 (A)
sel_A1: ROW_VERT/1X2.1, U3.11 (A)
sel_B: ROW_VERT/1X1.2, U2.10 (B)
sel_B1: ROW_VERT/1X2.2, U3.10 (B)
sel_C: ROW_VERT/1X1.3, U2.9 (C)
sel_C1: ROW_VERT/1X2.3, U3.9 (C)

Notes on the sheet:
Short circuit protection for each Cell https://www.youtube.com/watch?v=LdbDOMj07Gg
Optocoupler

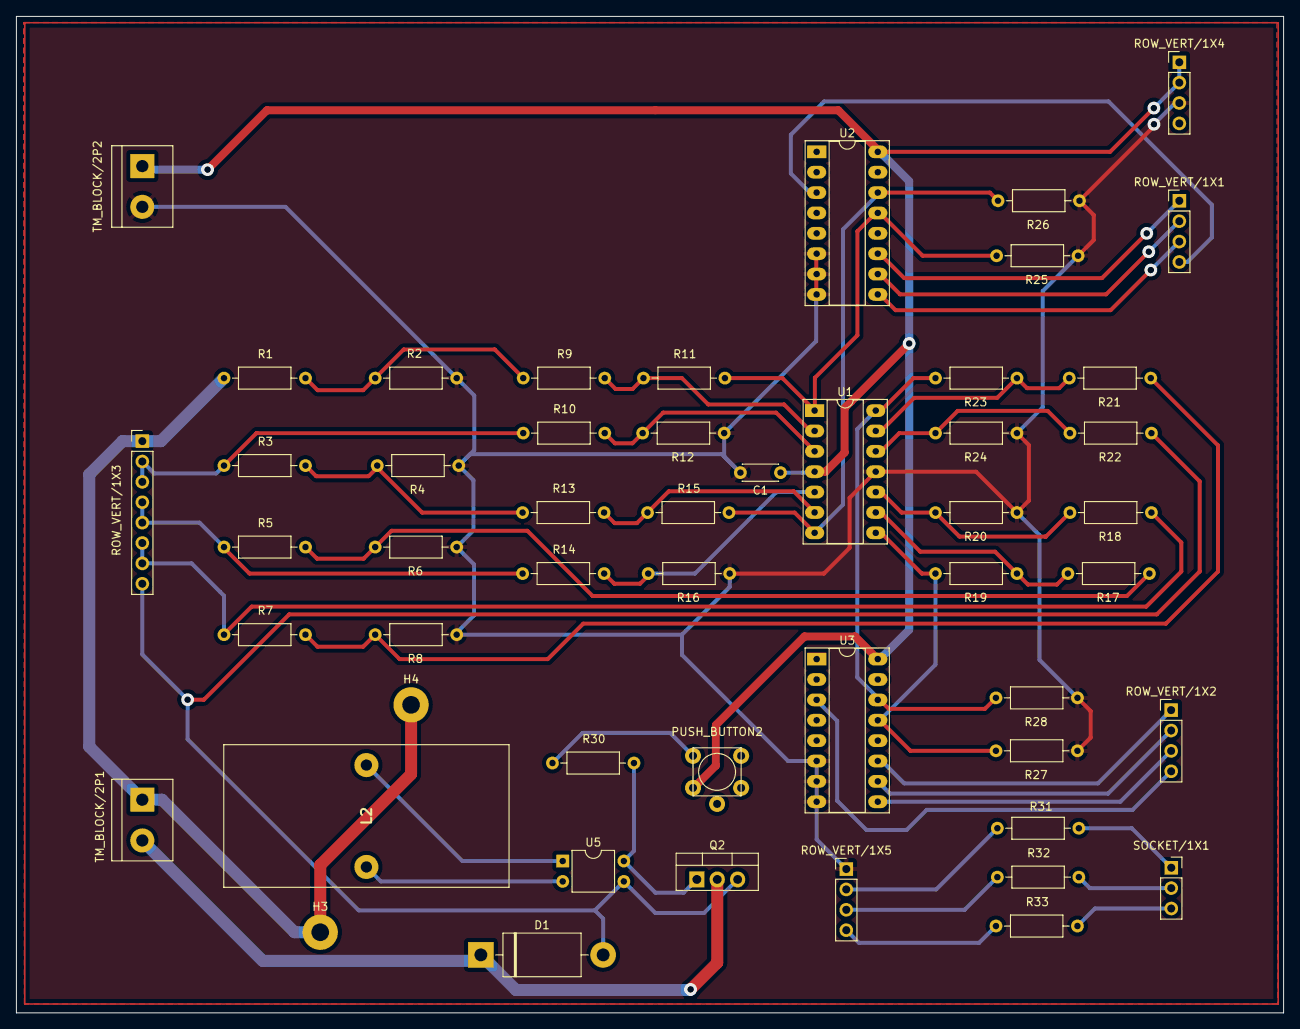
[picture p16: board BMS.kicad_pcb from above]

Board: 2 copper layers, 158.0 x 124.2 mm, 51 parts (0 on the bottom side), 42 nets.

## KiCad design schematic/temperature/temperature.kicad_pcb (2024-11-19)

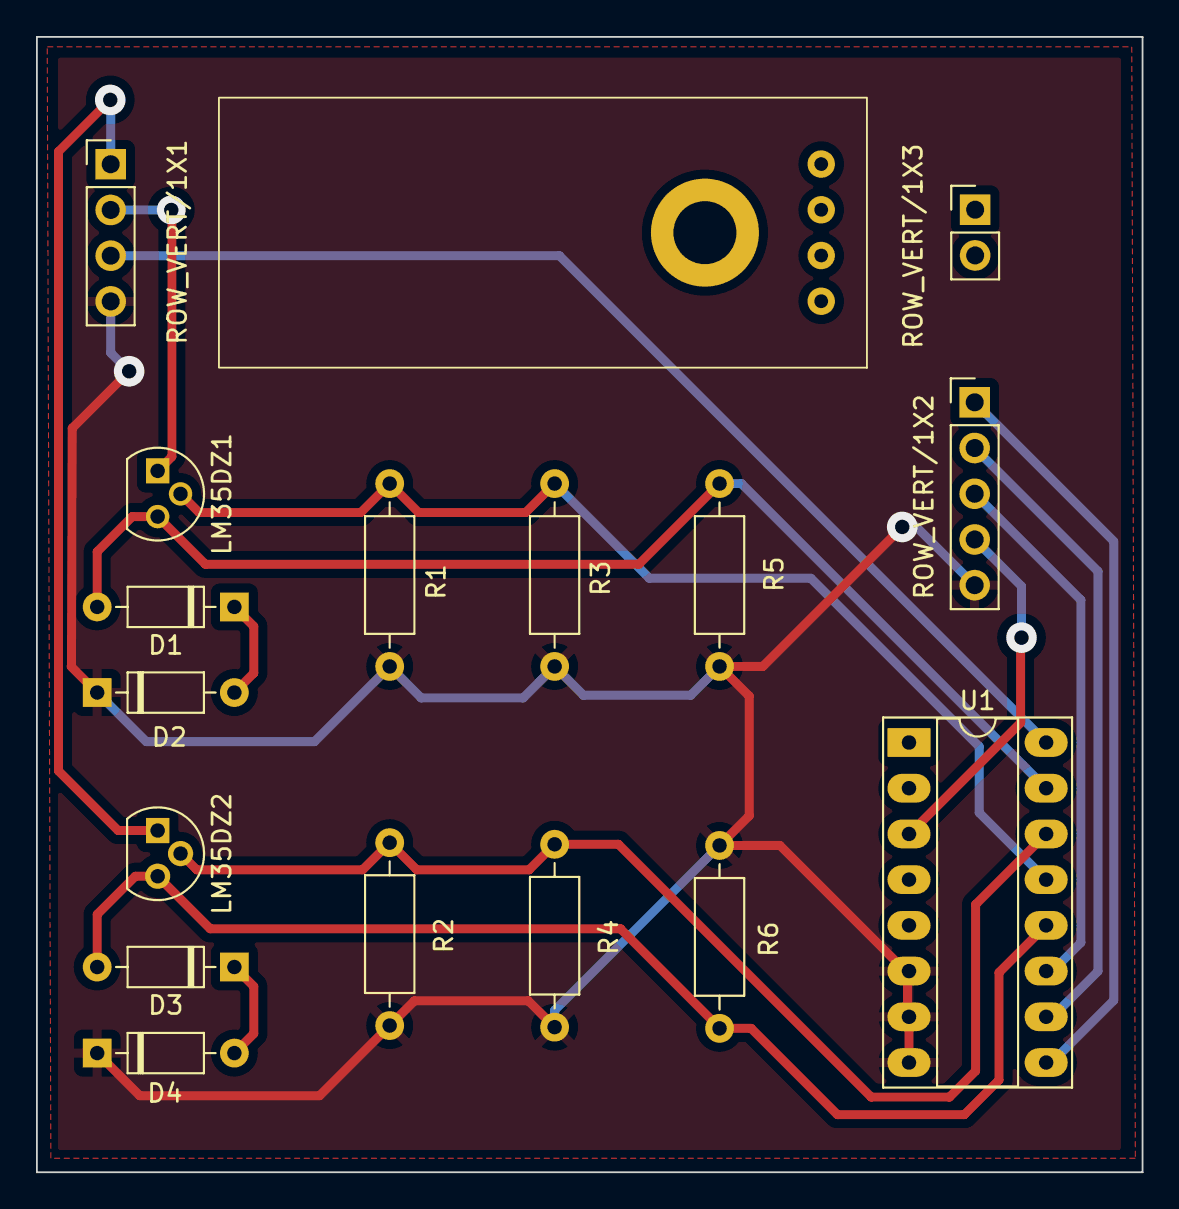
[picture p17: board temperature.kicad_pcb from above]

Board: 2 copper layers, 61.4 x 63.1 mm, 17 parts (0 on the bottom side), 14 nets.

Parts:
A1: Flame_KY026; KY026
D1, D2, D3, D4: 1N4148; D_DO-35_SOD27_P7.62mm_Horizontal
LM35DZ1, LM35DZ2: LM35DZ_TO92; TO-92
R1, R2: 18k; R3_5W
R3, R4, R5, R6: 10k; R3_5W
ROW_VERT/1X1: ROW_VERT_1X4; ROW_VERT_1x4
ROW_VERT/1X2: ROW_VERT_1X5; ROW_VERT_1x5
ROW_VERT/1X3: ROW_VERT_1X2; ROW_VERT_1x2
U1: CD4051B; DIP-16_W7.62mm_Socket_LongPads

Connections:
+5V: ROW_VERT/1X1.3, U1.16 (VDD)
GND: D2.1 (K), D4.1 (K), R1.1, R2.1, R3.1, R4.1, R5.1, R6.1, ROW_VERT/1X1.4, ROW_VERT/1X2.5, U1.6 (INH), U1.7 (VEE), U1.8 (VSS)
unnamed: D1.2 (A), LM35DZ1.3 (GND), R5.2, U1.15 (X2)
unnamed: D1.1 (K), D2.2 (A)
unnamed: D3.2 (A), LM35DZ2.3 (GND), R6.2, U1.12 (X3)
unnamed: D3.1 (K), D4.2 (A)
unnamed: LM35DZ1.2 (Vout), R1.2, R3.2, U1.13 (X0)
unnamed: LM35DZ2.2 (Vout), R2.2, R4.2, U1.14 (X1)
V_cell12: LM35DZ1.1 (+VS), ROW_VERT/1X1.2
V_cell34: LM35DZ2.1 (+VS), ROW_VERT/1X1.1
V_temperature: ROW_VERT/1X2.4, U1.3 (X)
sel_A: ROW_VERT/1X2.3, U1.11 (A)
sel_B: ROW_VERT/1X2.2, U1.10 (B)
sel_C: ROW_VERT/1X2.1, U1.9 (C)

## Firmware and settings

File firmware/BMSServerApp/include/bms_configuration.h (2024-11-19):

#pragma once
#include "stm32l1xx.h"

/* MODBUS Configuration */
#define SLAVE_ADDR 0x01 // Modbus slave address for the device
#define FUNCTION_CODE 0x04 // Modbus function code to read input registers
#define START_ADDR 0x00 // Starting address of the register to read
#define NUM_REGISTERS 8 // Number of registers to read in a single request
#define RESPONSE_BYTE_COUNT (NUM_REGISTERS * 2) // Number of bytes in the response (2 bytes per register)
#define MAX_REGISTERS 10 // Maximum number of registers that can be handled
#define BUFFER_SIZE 20 // Buffer size for Modbus communication

/* ADC Convert Configuration */
#define ADC_MAX_VALUE 4095 // Maximum value for a 12-bit ADC (2^12 - 1)
#define REF_VOLT_ADC 3300  // Reference voltage for the ADC in millivolts
#define GAIN 351 // Amplifier gain multiplied by 10 to retain precision without using float (represents 35.1)
#define R_SHUNT 10 // Shunt resistance value in milliohms (0.01 ohms = 10 milliohms)
#define CURRENT_CALIBRATION_GAIN 993 // Calibration gain for current calculation (scaled to avoid floating-point operations)
#define CURRENT_CALIBRATION_OFFSET -5 // Calibration offset for current in milliamperes (scaled to avoid floating-point operations)

/* Mosfet Control Configuration */
#define SHORT_CIRCUIT_THRESHOLD 50000 // Threshold for short-circuit detection in milliamperes
#define OVERCURRENT_THRESHOLD 9000 // Threshold for overcurrent detection in milliamperes
#define HIGH_CURRENT_THRESHOLD 1000 // Threshold for high current in milliamperes (for body diode protection)

#define DISCHARGE_OVER_TEMPERATURE_THRESHOLD 4000       // Over-temperature threshold in hundredths of degrees Celsius (e.g., 4500 = 45.00°C) (for discharging)
#define DISCHARGE_UNDER_TEMPERATURE_THRESHOLD -2000     // Under-temperature threshold in hundredths of degrees Celsius (e.g., -2000 = -20.00°C) (for discharging)

#define CHARGE_OVER_TEMPERATURE_THRESHOLD 3000 // Over-temperature threshold in hundredths of degrees Celsius (e.g., 4500 = 45.00°C)  (for charging)
#define CHARGE_UNDER_TEMPERATURE_THRESHOLD 500 // Under-temperature threshold in hundredths of degrees Celsius (e.g., -2000 = -20.00°C) (for charging)

#define LOW_VOLTAGE_THRESHOLD 2800 // Low voltage threshold per cell in millivolts
#define HIGH_VOLTAGE_THRESHOLD 3200 // High voltage threshold per cell in millivolts

#define DEEP_SLEEP_TEMP_THRESHOLD -4000 // -40.00°C in hundredths of a degree
#define WAKE_UP_TEMP_THRESHOLD -2000    // -20.00°C in hundredths of a degree

#ifdef TEST
#define DEBOUNCE_DELAY_MS 10 // Debounce delay in milliseconds for testing (reduced to speed up testing)
#else
#define DEBOUNCE_DELAY_MS 1000 // Debounce delay in milliseconds for normal operation
#endif

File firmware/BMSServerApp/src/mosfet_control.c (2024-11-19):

#include "stm32l1xx.h"
#include "bms_configuration.h"
#include "system.h"
#include "utils.h"
#include "usart2.h"
#include "mosfet_control.h"

#include <time.h>
#include <math.h>

static int charge_mosfet_pin_state = 0;
static int discharge_mosfet_pin_state = 0;
static system_state_t previous_system_state = STATE_BOTH_OFF;
static mosfet_state_t previous_charge_mosfet_state = MOSFET_OFF;
static mosfet_state_t previous_discharge_mosfet_state = MOSFET_OFF;

static bool body_diode_fault_flag = false;
static bool immediate_action_required = false;
static uint8_t fault_bitmask = 0x00;
static uint32_t last_switch_time = 0;
uint32_t current_mock_time = 0;

//Resets the MOSFET control logic to initial states.
// This function resets the MOSFET states and clears any existing fault flags.
void reset_mosfet_control_logic() {
    previous_charge_mosfet_state = MOSFET_OFF;
    previous_discharge_mosfet_state = MOSFET_OFF;

    fault_bitmask = 0x00;
    body_diode_fault_flag = false;
    immediate_action_required = false;

    last_switch_time = get_current_time_ms();

    set_charge_mosfet(MOSFET_OFF);
    set_discharge_mosfet(MOSFET_OFF);
}

// Initialize MOSFET GPIO pins
void mosfet_init(void) {
    // Enable GPIO Port Clock
    RCC->AHBENR |= RCC_AHBENR_GPIOBEN;

    // Set CHARGE_MOSFET_PIN and DISCHARGE_MOSFET_PIN as output
    GPIOB->MODER &= ~((0x3 << (CHARGE_MOSFET_PIN * 2)) | (0x3 << (DISCHARGE_MOSFET_PIN * 2))); // Clear mode bits
    GPIOB->MODER |= ((0x1 << (CHARGE_MOSFET_PIN * 2)) | (0x1 << (DISCHARGE_MOSFET_PIN * 2)));  // Set to output mode

    // Set output type as push-pull
    GPIOB->OTYPER &= ~((1U << CHARGE_MOSFET_PIN) | (1U << DISCHARGE_MOSFET_PIN));

    // Set speed to low
    GPIOB->OSPEEDR &= ~((0x3 << (CHARGE_MOSFET_PIN * 2)) | (0x3 << (DISCHARGE_MOSFET_PIN * 2)));

    // Set no pull-up, no pull-down
    GPIOB->PUPDR &= ~((0x3 << (CHARGE_MOSFET_PIN * 2)) | (0x3 << (DISCHARGE_MOSFET_PIN * 2)));
}

// Main MOSFET control logic function
void mosfet_control_logic(sensor_values_t* sensor_values) {
    if (sensor_values == NULL) {
        return; // Prevent dereferencing a NULL pointer
    }

    uint32_t current_time = get_current_time_ms();
    bool debounce_passed = (current_time - last_switch_time) >= DEBOUNCE_DELAY_MS;

    // Use the higher of charge or discharge current for protections
    uint16_t current_max = (sensor_values->battery_current_charge > sensor_values->battery_current_discharge)
							? sensor_values->battery_current_charge : sensor_values->battery_current_discharge;
	int16_t temperature_max = (sensor_values->battery_temperature > sensor_values->battery_temperature_alt)
							  ? sensor_values->battery_temperature : sensor_values->battery_temperature_alt;
	int16_t temperature_min = (sensor_values->battery_temperature < sensor_values->battery_temperature_alt)
							  ? sensor_values->battery_temperature : sensor_values->battery_temperature_alt;

    // Update fault flags based on sensor values
    check_body_diode_protection(current_max);
    check_overcurrent(current_max);
    check_over_temperature_protection(temperature_max);
    check_low_temperature_protection(temperature_min);
    check_voltage_protection(sensor_values->cell_voltage);

    // Determine system state based on all available sensor data
    system_state_t current_system_state = determine_system_state();

    // Update MOSFET states if debounce has passed and there are no active faults
    if (immediate_action_required) {
        update_mosfet_states(current_system_state, current_time);
        previous_system_state = current_system_state;
        immediate_action_required = false; // Reset the flag
        last_switch_time = current_time;   // Update last switch time
    } else if (debounce_passed) {
        if (current_system_state != previous_system_state) {
            update_mosfet_states(current_system_state, current_time);
            previous_system_state = current_system_state;
            last_switch_time = current_time;
        }
    } else {
        // Debounce not passed, revert to previous MOSFET states
        if (previous_charge_mosfet_state != charge_mosfet_pin_state) {
            set_charge_mosfet(previous_charge_mosfet_state);
        }
        if (previous_discharge_mosfet_state != discharge_mosfet_pin_state) {
            set_discharge_mosfet(previous_discharge_mosfet_state);
        }
    }
}

void EXTI0_IRQHandler(void) {
    // Check if the interrupt was triggered by line 0
    if (EXTI->PR & (1 << 0)) {
        // Clear the interrupt flag by writing 1 to it
        EXTI->PR |= (1 << 0);

        if (system_in_deep_sleep_mode) {
            exit_deep_sleep();
        } else {
            short_circuit_isr();
        }
    }
}

// Interrupt service routine for short-circuit protection
void short_circuit_isr() {
    // Set the fault bit for short-circuit detection immediately
    fault_bitmask |= (1 << 0); // Set bit 0 for short-circuit

    // Immediately turn off both MOSFETs for safety
    set_charge_mosfet(MOSFET_OFF);
    set_discharge_mosfet(MOSFET_OFF);
    previous_charge_mosfet_state = MOSFET_OFF;
    previous_discharge_mosfet_state = MOSFET_OFF;
}

void check_overcurrent(uint16_t current_max) {
    if (current_max >= OVERCURRENT_THRESHOLD) {
        fault_bitmask |= (1 << 1); // Set bit 1 for overcurrent
    } else {
        fault_bitmask &= ~(1 << 1); // Clear bit 1
    }
}

void check_body_diode_protection(uint16_t current) {
    if (current >= HIGH_CURRENT_THRESHOLD) {
        if (!body_diode_fault_flag) {
            body_diode_fault_flag = true;
            immediate_action_required = true;
        }
    } else {
        if (body_diode_fault_flag) {
            body_diode_fault_flag = false;
            immediate_action_required = true;
        }
    }
}

void check_over_temperature_protection(int16_t temperature) {
    if (temperature > DISCHARGE_OVER_TEMPERATURE_THRESHOLD) {
        fault_bitmask |= (1 << 2);
    } else {
        fault_bitmask &= ~(1 << 2);
    }
    if (temperature > CHARGE_OVER_TEMPERATURE_THRESHOLD && temperature <= DISCHARGE_OVER_TEMPERATURE_THRESHOLD) {
        fault_bitmask |= (1 << 3);
    } else {
        fault_bitmask &= ~(1 << 3);
    }
}

void check_low_temperature_protection(int16_t temperature) {
    if (temperature < DISCHARGE_UNDER_TEMPERATURE_THRESHOLD) {
        fault_bitmask |= (1 << 4);
    } else {
        fault_bitmask &= ~(1 << 4);
    }
    if (temperature >= DISCHARGE_UNDER_TEMPERATURE_THRESHOLD && temperature < CHARGE_UNDER_TEMPERATURE_THRESHOLD) {
        fault_bitmask |= (1 << 5);
    } else {
        fault_bitmask &= ~(1 << 5);
    }
}
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

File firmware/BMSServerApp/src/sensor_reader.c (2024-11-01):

#include "sensor_reader.h"
#include "adc.h"
#include "adc_converter.h"
#include "mux.h"
#include "system.h"
#include "utils.h"

#define FILTER_LENGTH 5

// Buffers to store raw ADC readings for filtering
static int16_t temp_buffer_1[FILTER_LENGTH] = {0};
static int16_t temp_buffer_2[FILTER_LENGTH] = {0};
static uint16_t current_buffer_1[FILTER_LENGTH] = {0};
static uint16_t current_buffer_2[FILTER_LENGTH] = {0};
static uint16_t voltage_buffer_1[4][FILTER_LENGTH] = {0};

void read_temperature_sensors(sensor_values_t *sensor_data) {
    // Read temperature from the first LM35 sensor
    uint16_t output_adc_1 = read_mux_channel(0, MUX_TEMP_SELECT_PIN_MASK, ADC_CHANNEL_TEMP_SENSOR); // Vout LM35 sensor 1
    uint16_t diode_adc_1 = read_mux_channel(2, MUX_TEMP_SELECT_PIN_MASK, ADC_CHANNEL_TEMP_SENSOR); // Diode voltage LM35 sensor 1
    for (int i = FILTER_LENGTH - 1; i > 0; i--) {
		temp_buffer_1[i] = temp_buffer_1[i - 1];
	}
	temp_buffer_1[0] = adc_convert_battery_temp(output_adc_1, diode_adc_1);
	sensor_data->battery_temperature = (int16_t)moving_average_filter((int32_t *)temp_buffer_1, FILTER_LENGTH);
#ifdef TEST
	sensor_data->battery_temperature = 3456;
#endif

    // Read temperature from the second LM35 sensor
    uint16_t output_adc_2 = read_mux_channel(1, MUX_TEMP_SELECT_PIN_MASK, ADC_CHANNEL_TEMP_SENSOR); // Vout LM35 sensor 2
    uint16_t diode_adc_2 = read_mux_channel(3, MUX_TEMP_SELECT_PIN_MASK, ADC_CHANNEL_TEMP_SENSOR); // Diode voltage LM35 sensor 2
    for (int i = FILTER_LENGTH - 1; i > 0; i--) {
		temp_buffer_2[i] = temp_buffer_2[i - 1];
	}
	temp_buffer_2[0] = adc_convert_battery_temp(output_adc_2, diode_adc_2);
	sensor_data->battery_temperature_alt = (int16_t)moving_average_filter((int32_t *)temp_buffer_2, FILTER_LENGTH);
#ifdef TEST
	sensor_data->battery_temperature_alt = 3123;
#endif
}

void read_current_sensors(sensor_values_t *sensor_data)
{
    // Read charging current
    uint16_t current_adc_1 = read_mux_channel(0, MUX_CURR_SELECT_PIN_MASK, ADC_CHANNEL_SHUNT_CURRENT); // Charging current
    for (int i = FILTER_LENGTH - 1; i > 0; i--) {
		current_buffer_1[i] = current_buffer_1[i - 1];
	}
	current_buffer_1[0] = adc_convert_battery_current(current_adc_1);
	sensor_data->battery_current_charge = (uint16_t)moving_average_filter((int32_t *)current_buffer_1, FILTER_LENGTH);
#ifdef TEST
	sensor_data->battery_current_charge = 90;
#endif

    // Read discharging current
    uint16_t current_adc_2 = read_mux_channel(1, MUX_CURR_SELECT_PIN_MASK, ADC_CHANNEL_SHUNT_CURRENT); // Discharging current
    for (int i = FILTER_LENGTH - 1; i > 0; i--) {
        current_buffer_2[i] = current_buffer_2[i - 1];
    }
    current_buffer_2[0] = adc_convert_battery_current(current_adc_2);
    sensor_data->battery_current_discharge =  (uint16_t)moving_average_filter((int32_t *)current_buffer_2, FILTER_LENGTH);
#ifdef TEST
    sensor_data->battery_current_discharge = 120;
#endif
}


void read_voltage_sensors(sensor_values_t *sensor_data)
{
    uint16_t cell_voltage_adc;

    // Read voltage from first multiplexer (Battery 1 and Battery 2)
    for (int channel = 0; channel < 2; ++channel) {
        cell_voltage_adc = read_mux_channel(channel, MUX_BATT1_SELECT_PIN_MASK, ADC_CHANNEL_VOLTAGE_MEASUREMENT_1);

        // Store and filter the readings
        for (int i = FILTER_LENGTH - 1; i > 0; i--) {
            voltage_buffer_1[channel][i] = voltage_buffer_1[channel][i - 1];
        }
        voltage_buffer_1[channel][0] = adc_convert_cell_voltage(cell_voltage_adc);
        sensor_data->cell_voltage[channel] =  (uint16_t)moving_average_filter((int32_t *)voltage_buffer_1[channel], FILTER_LENGTH);
#ifdef TEST
        sensor_data->cell_voltage[channel] = 2890;
#endif
    }

    // Read voltage from second multiplexer (Battery 3 and Battery 4)
    for (int channel = 0; channel < 2; ++channel) {
        cell_voltage_adc = read_mux_channel(channel, MUX_BATT2_SELECT_PIN_MASK, ADC_CHANNEL_VOLTAGE_MEASUREMENT_2);

        // Store and filter the readings
        for (int i = FILTER_LENGTH - 1; i > 0; i--) {
            voltage_buffer_1[channel + 2][i] = voltage_buffer_1[channel + 2][i - 1];
        }
        voltage_buffer_1[channel + 2][0] = adc_convert_cell_voltage(cell_voltage_adc);
        sensor_data->cell_voltage[channel + 2] =  (uint16_t)moving_average_filter((int32_t *)voltage_buffer_1[channel + 2], FILTER_LENGTH);
#ifdef TEST
        sensor_data->cell_voltage[channel + 2] = 2756;
#endif
    }
}

void read_all_sensors(sensor_values_t *sensor_data)
{
    read_temperature_sensors(sensor_data);
    read_current_sensors(sensor_data);
    read_voltage_sensors(sensor_data);
}

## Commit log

2024-09-08 Initialized bms project in truestudio.
    Issue : SCRUM-7
    [usart2.c]
2024-09-09 Ignore files in firmware/.metadata/. Add basic libs of stm32 functions.
    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
    [adc.c, usart1.c, utils.c]
2024-09-10 Add LM324N opamp prototypying. Designed calibration method.
    Issue : SCRUM-5
2024-09-14 Add modbus slave lib, update ADC convert.
    Issue: SCRUM-7
    [adc.c, adc_converter.c, bms_configuration.h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]
2024-09-17 Add main supporting mock values using modbus RTU Function code 04 to communicate with test_slave. Add test_slave. Restructure include, src and libs.
    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
    [usart2.c]
2024-09-18 Add multiplexer code. Tested with PA5 led blink to select channal. Issue: SCRUM-7
    [bms_configuration.h, mux.c, utils.c]
2024-09-19 SCRUM-2 add draft schematic
2024-09-19 SCRUM-6 Added a python prototype file for grafana usage
2024-09-21 Create cross-compilation steps using cmake and ninja. Updated README for relevant changes.
    Issue: SCRUM-15
    [bms_configuration.h, mux.c]
2024-09-22 Add code draft for integration and testing. ISSUE: SCRUM-15
    [adc.c, adc_converter.c, usart1.c]
2024-09-25 Add adc basic and adc_converter. Add mock adc value testing. SCRUM-19
2024-09-27 Add temperature measurement prototyping documentation.
2024-09-28 Restructured modbus header and src file. Modified tempereature sensor adc converter. SCRUM-19
2024-10-02 Create test_current_meas
    Initial test code for shunt resistor measurement of current.
2024-10-02 Update and rename MOSFETCONTROL.c to test_mosfet_control.c
2024-10-06 Refactor adc, mux, modbus and sytem pin configuration. Seperated TEST build. SCRUM-20
2024-10-06 Init implementation of mosfet control logic. SCRUM-20
2024-10-12 Update mosfet control logic supporting overcurrent overtemperature overvoltage shortcircuit and over diode current. Init mosfet control test. SCRUM-20
    [adc.c, bms_configuration.h, mosfet_control.c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]
2024-10-13 Add mosfet control tests. SCRUM-20
2024-10-13 Update mosfet_control logic using bit mask for fault mask. SCRUM-20
2024-11-01 Scrum 14 design state machine integrated with mosfet control logic (#9)
    * Add mutiplexer select logic to read adc according
    to different module hardware design.
    SCRUM-14
    * Update cmake-multi-platform.yml
    * Update cmake-multi-platform.yml
    * Replaced float calculation by all interger calculation.
    Applied moving average filter for adc read values.
    Added function declare and introduction.
    Init intergration test, tobe continue.
    SCRUM-14
    * Add deepsleep mode.
    Add actual current calibration number.
    SCRUM-14
    [BMSClientApp_2.py, adc.c, adc_converter.c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]
2024-11-03 Update body diode protection critical case. SCRUM-23
2024-11-03 Update actual implementation according to passed test suit for mosfet control. SCRUM-23
2024-11-19 Scrum 2 create schematic for pcb (#11)
    * SCRUM-2-add schematics for 4 modules
    * add new schematics for 4 modules, pcb layout of mosfet and current simulation
    * upload temperature schematic
    * SCRUM-2 add the updated schematics and simulation
    ---------
    [BMS.kicad_pcb, BMS.kicad_sch, current.kicad_pcb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]
